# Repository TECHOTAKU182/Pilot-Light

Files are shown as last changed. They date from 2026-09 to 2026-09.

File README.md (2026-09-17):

# Pilot Light

一个紧凑型 USB RGB 状态信号灯的开源硬件项目。当前设计版本为 **SL25 Rev B**：通过 CH552G 控制一颗位于正面中心的 WS2812B-V5，使用单个直径 24 mm 的扩散灯窗显示红、黄、绿等状态。

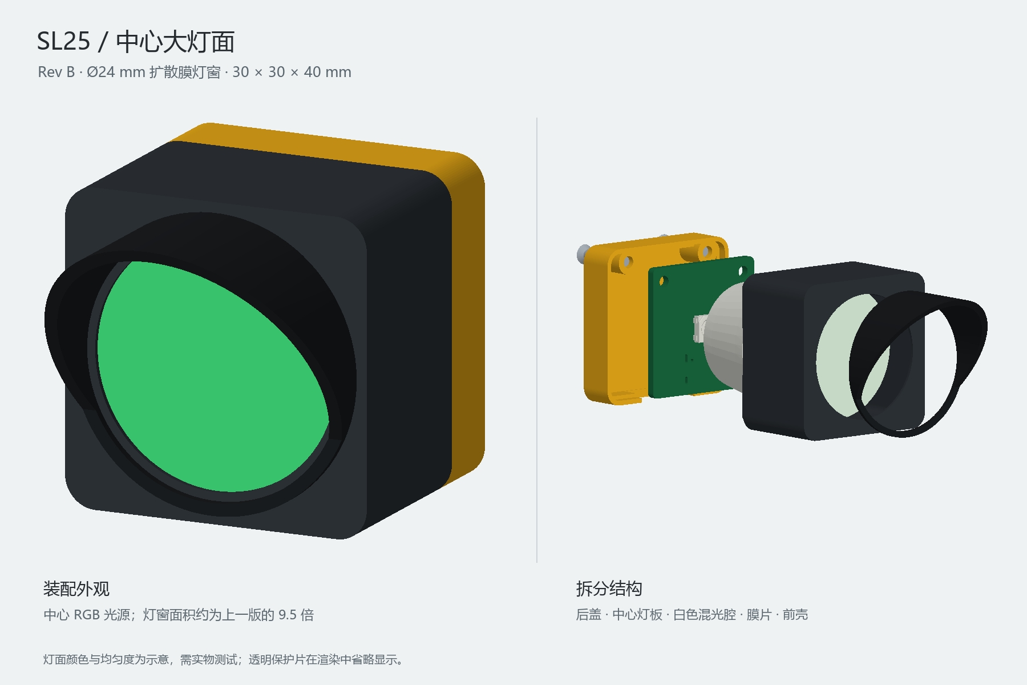
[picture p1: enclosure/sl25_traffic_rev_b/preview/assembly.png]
SL25 Rev B assembly preview


> 本仓库包含可编辑的 PCB、外壳和制造文件，但尚未完成实物打样、光学测试、USB 功能验证或电脑状态采集软件。制造与使用前请自行复核并完成测试。

## 当前设计

| 项目 | SL25 Rev B 规格 |
| --- | --- |
| PCB | 25 x 25 mm、双层、1.6 mm 厚 |
| 光源 | 正面中心 WS2812B-V5 RGB LED |
| 控制器 | CH552G，LED 数据输出为 P1.5 |
| 接口 | 背面 USB-C，USB 2.0 全速原型电路 |
| 外壳 | 30 x 30 x 40 mm |
| 灯窗 | 正面中心直径 24 mm，PET 扩散膜与透明 PC 保护片 |
| 遮光檐 | 顶部前伸 15 mm，两侧连续收短 |

该设计的光学结构从外到内依次为：黑色遮光帽、透明 PC 保护片、PET 扩散膜、泡棉压圈、白色混光腔与中心 RGB LED。白色混光腔是获得较均匀光效的必要零件，不能以黑色打印件替代。

## 仓库结构

| 路径 | 内容 |
| --- | --- |
| [`hardware/sl25_rev_b/`](hardware/sl25_rev_b/) | 当前 Rev B KiCad 工程、BOM、Gerber、贴片坐标、3D 模型与检查报告 |
| [`enclosure/sl25_traffic_rev_b/`](enclosure/sl25_traffic_rev_b/) | 当前 Rev B FreeCAD 工程、STEP、STL、光学片裁切模板与装配说明 |
| [`firmware/ch552_ws2812_demo/`](firmware/ch552_ws2812_demo/) | 用于焊后点灯检查的最小 CH552G 示例程序 |
| [`hardware/reference/`](hardware/reference/) | 器件数据手册和参考图纸 |
| [`SL25-RevB-complete.zip`](SL25-RevB-complete.zip) | Rev B 完整交付包 |
| [`hardware/SL25-RevB-gerbers.zip`](hardware/SL25-RevB-gerbers.zip) | Rev B PCB 制板文件包 |
| [`enclosure/SL25-Traffic-STL-RevB.zip`](enclosure/SL25-Traffic-STL-RevB.zip) | Rev B 3D 打印和膜片裁切文件包 |

`hardware/sl25/` 与 `enclosure/sl25_traffic/` 为历史 Rev A 文件，仅供参考。Rev A 和 Rev B 的 LED、元件安装面、外壳及控制方式不兼容，不能混用。

## 制造与装配

1. 使用 `hardware/SL25-RevB-gerbers.zip` 下单 PCB；建议规格为 FR-4、2 层、1.6 mm、1 oz 铜。
2. 根据 [`hardware/sl25_rev_b/BOM.csv`](hardware/sl25_rev_b/BOM.csv) 和 [`MATERIALS.md`](hardware/sl25_rev_b/MATERIALS.md) 采购并装配；所有元件和 USB-C 均在 PCB 背面，只有 WS2812B-V5 位于正面。
3. 打印 Rev B 的四个外壳件。前壳和遮光帽使用黑色材料，混光腔必须使用不透光白色材料；建议 PETG、0.4 mm 喷嘴、0.16-0.20 mm 层高。
4. 按 `cut_templates/` 中 1:1 SVG 裁切直径 26 mm 的透明 PC 保护片、PET 扩散膜和泡棉环；先测量模板中的 10 x 10 mm 校准框。
5. 参考 [外壳装配说明](enclosure/sl25_traffic_rev_b/README.md) 完成装配。需要两颗 M2 x 12、头径不超过 4.0 mm 的 90 度沉头螺丝。
6. 使用 [`firmware/ch552_ws2812_demo/`](firmware/ch552_ws2812_demo/) 的台架程序确认红、绿、蓝、黄依次点亮，再进行完整功能开发。

完整尺寸、材料规格、打印方向、光学叠层和拆装步骤见 [外壳 README](enclosure/sl25_traffic_rev_b/README.md)。电路、USB/LED 引脚、制造规则和检验结果见 [PCB README](hardware/sl25_rev_b/README.md)。

## 开发与重建

- PCB 使用 KiCad 10。更新设计时，先保留手工修改，再依次运行 `hardware/generate_rev_b.py`、`hardware/route_rev_b.py` 和 `hardware/finish_board.py`；这些生成流程会覆盖已有输出。
- 外壳使用 FreeCAD。修改 `enclosure/sl25_traffic_rev_b/parameters.json` 后，依次运行 `build.py`、`finish_cad.py`、`render.py` 和 `cut_templates.py`。
- 固件使用 SDCC，并需要 WCH CH55X EVT 提供的启动文件。示例程序只用于点灯检查，正式固件应加入 USB 枚举、主机命令超时关灯、USB 挂起关灯和看门狗。

## 验证状态与限制

仓库中的 ERC、DRC、制造文件、模型资产和几何干涉检查已通过，但以下事项尚待实物确认：

- USB 电气性能、枚举和 USB-C 兼容性
- LED 的 WS2812 时序、功耗、温升和各颜色亮度
- 扩散膜下的均匀度、色斑和黄色配比
- 3D 打印公差、膜材厚度、螺丝配合和机械耐久

本项目不是通过认证的交通信号灯，也不应在安全关键或监管用途部署。

## 许可证

尚未指定许可证。在许可证补充前，请先联系仓库所有者确认使用、修改和分发权限。

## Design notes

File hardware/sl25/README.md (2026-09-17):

# SL25 状态灯 PCB，Rev A

这是一块面向个人原型的 25 × 25 mm 双层 USB 状态灯 PCB，可用于正面宽、高均不超过 30 mm 的外壳。当前完成硬件设计和软件规则检查，尚未制作、焊接或实测。固件、Windows 状态采集程序和外壳工程不包含在本次交付中。

## 打开工程

使用 KiCad 10 打开 `sl25.kicad_pro`，分别进入原理图和 PCB 编辑器。符号、封装和所用 STEP 模型均随工程提供。KiCad 三维查看器可查看装配效果。

| 文件 | 内容 |
| --- | --- |
| `sl25.kicad_sch` | 单页原理图 |
| `sl25.kicad_pcb` | 已布线、铺铜的 PCB |
| `BOM.csv` | 逐项材料表，含准确型号与安装面 |
| `MATERIALS.md` | 中文采购及装配说明 |
| `checks/erc.rpt`、`checks/drc.rpt` | 最终规则检查报告 |
| `fabrication/` | Gerber、独立 PTH/NPTH 钻孔、贴装坐标 |
| `mechanical/sl25.step` | 含元件的装配 STEP，供外壳设计参考 |
| `mechanical/interface.json` | 板框、安装孔和接口位置 |
| `preview/` | 原理图 SVG 及 PCB 正反面、立体预览 |

本文件夹中的材料表替代之前讨论的 Pico 开发板和洞洞板采购方案。USB-C 插座必须匹配指定封装，不能仅凭“16 脚 Type-C”购买替代件。

## 电路

- USB-C 仅使用 USB 2.0 数据与 5 V 供电，CC1、CC2 各自用 5.1 kΩ 电阻接地。没有 USB PD 升压、电池或外部电源接口。
- CH552G 使用 SOP-16 窄体封装、内部振荡器和内部 USB 上拉。VCC 接 USB 5 V；V33 仅接 100 nF 去耦，不能短接到 5 V。
- USBLC6-2SC6 在背面保护 D+、D-；C4 是其电源去耦。插座金属壳直接接 GND，壳体焊脚直接接地铜皮。
- 单颗共阴 RGB 灯的每个阳极分别串 1 kΩ，限流后由 MCU GPIO 驱动。以 5.25 V 和 1% 电阻下限估算，即使忽略 LED 压降，单路电流也不超过 5.31 mA。
- JP1 平时保持断开；通过 10 kΩ 将 D+ 临时拉到 5 V，在上电时请求兼容工厂 USB ISP 的下载模式。购买带工厂 USB ISP 的 CH552G。TP3–TP6 保留专用编程器信号，不能当作通用 SPI 外设接口。
- R7 将高有效 RESET 下拉到 GND。固件仍应采用上电复位和看门狗。

| 功能 | CH552G 物理脚 | GPIO | 备注 |
| --- | --- | --- | --- |
| 红灯 | 3 | P1.5 | PWM1；高电平亮 |
| 绿灯 | 11 | P3.4 | PWM2；高电平亮 |
| 蓝灯 | 9 | P1.1 | 普通 GPIO，默认关闭 |
| USB D+ | 12 | P3.6 | USB 功能 |
| USB D- | 13 | P3.7 | USB 功能 |
| RESET | 6 | RST | 高有效 |

红加绿形成黄色。PWM 占空比需在样板和最终灯罩上调整，不能保证两路相同占空比就得到视觉上均匀的黄色。

## 固件与电脑端约定

建议后续固件使用 USB HID 接收颜色、亮度和灯效命令，Windows 程序通过 HID 库发送，无需增加 USB 转串口芯片。未配置、USB 挂起和主机命令超时应关闭 LED；初始化时先将三路输出置低，再使能输出，红绿用硬件 PWM，蓝色默认不用。

USB VID/PID 和描述符在固件阶段确定，不能未经授权用于发布产品。USB 功耗描述和挂起电流必须与实测匹配。当前电路未验证 USB 枚举、信号质量、EMC 或 ESD 性能；放置保护器件不等于通过系统级认证。

Windows 桌面版 Codex 的实时状态来源仍需单独验证。PCB 本身只接收灯光命令，不会自动读取 Codex。

## 制板与机械

建议首批 5 块样板：双层 FR-4、1.6 mm、1 oz 铜、绿色阻焊、白色丝印；优先选择平整表面处理，USB-C 手焊可选沉金。没有阻抗控制声明。

布线宽度 0.20 mm，设计最小铜间距 0.15 mm；过孔 0.60 / 0.30 mm。安装孔 2.20 mm，LED 孔 0.90 mm；PTH 和 NPTH 分开导出。USB4105 厂家推荐焊盘到定位孔的最近距离约 0.194 mm，本项目孔到铜间距规则设为 0.18 mm；下单时需要工厂支持这一要求。没有通过忽略 DRC 错误来放行设计。

板框圆角半径 1 mm。以 PCB 左上角为平面坐标原点，X 向右、Y 向下：

| 项目 | 位置或尺寸，mm |
| --- | --- |
| PCB 外形 | 25 × 25 × 1.6 |
| H1、H2 安装孔 | (2.7, 2.7)、(22.3, 2.7)，孔径 2.2 |
| D1 光学中心 | (12.5, 3.5)，靠近板上边，不在板中心 |
| USB 插座封装原点 | (12.5, 21.15)，插拔方向朝下边 |
| USB 插座本体 | 厂家宽 8.94、长 7.35、高 3.31 |
| LED 引脚孔 | X=9.2615 / 11.4205 / 13.5795 / 15.7385；Y=3.5 |

建议外壳先按 30 × 30 × 25 mm 预留，厚度尚未与用户锁定。壁厚与装配间隙需在外壳建模时分配，底面需留出 U2、C4 和焊点空间。两个 M2 安装柱配合底部承托或导轨固定 PCB，避免 USB 插拔力只作用在焊脚上。

LED 需用工具夹住靠近封装的一段引脚，再将外侧引脚整形成 2.159 mm 间距，封装底面离板约 3 mm，不要紧贴树脂根部弯折。灯珠顶面及焊接公差在外壳内至少按板上方 12.5 mm 预留，再留混光距离。STEP 中 LED 为通用 KiCad 模型，蓝色外观只是模型材质；实际指定灯珠为透明 RGB。该模型不能替代实物高度和透光测试。

STEP 使用 PCB 左上角 `(100,100)` 作为导出原点；CAD 的 Y 轴可能与上述 PCB 屏幕坐标相反，导入后以安装孔和 USB 方向识别朝向。

## 验证状态

2026-09-05 使用 KiCad 10.0.6：ERC 为 0 错误、0 警告；DRC 为 0 违规、0 未连接、0 原理图一致性问题。检查了厂家引脚图、封装尺寸图和正反面三维预览。

这些是设计文件检查，不能替代打样验证。未执行固件烧录、供电测量、USB 插头正反插、亮度混色、热稳定、休眠恢复及外壳装配测试。USB 数据布线为短距离原型布线，未做阻抗提取或信号完整性仿真。

## 设计依据与库许可

- WCH CH552/CH551 数据手册 V1G，第 3–4、19、31–33、70 页；`../reference/CH552.pdf` 为 WCH 原文的 Adafruit 镜像。厂家入口：https://www.wch-ic.com/downloads/CH552DS1_PDF.html
- Kingbright WP154A4SUREQBFZGC，第 1–2 页：https://www.kingbrightusa.com/images/catalog/spec/WP154A4SUREQBFZGC.pdf
- GCT USB4105 厂家图纸：https://gct.co/files/drawings/usb4105.pdf
- ST USBLC6-2SC6：https://www.st.com/resource/en/datasheet/usblc6-2.pdf
- ch55xduino 工程及 USB ISP 上电方式：https://github.com/DeqingSun/ch55xduino
- 随附封装、STEP 模型来自 KiCad 官方库，适用 KiCad 库许可及其例外：https://www.kicad.org/libraries/license/ 。通用芯片模型只表示封装，并不代表芯片品牌或实物标识。

## 重新生成

已交付文件可以直接在 KiCad 中编辑。只有需要重新生成初始设计时才执行以下脚本；重新生成会覆盖手工改板结果，先保留自己的修改。

在项目根目录运行 KiCad 自带 Python：依次执行 `hardware/generate_board.py`、`hardware/route_board.py`、`hardware/finish_board.py`。默认工具路径是本机的 `E:/Kicard`，其他电脑可调整 `KICAD_FOOTPRINT_DIR`、`KICAD_3DMODEL_DIR`。渲染需要 KiCad 用户缓存目录可写，否则可能只显示裸板。

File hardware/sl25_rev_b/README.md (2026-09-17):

# SL25 Rev B：中心 RGB 光源 PCB

本版与 `../../enclosure/sl25_traffic_rev_b/` 外壳配套，取代 Rev A 的偏上小灯珠设计。**PCB 正面只有一颗位于几何中心的 WS2812B-V5，其他电子元件和 USB-C 均在背面。** 板框仍为 25×25 mm，双层、1.6 mm 厚，两个 M2 孔的位置保持原接口。

此版灯珠、电阻值、元件安装面和固件灯光控制方式均与 Rev A 不同。制板、买料和装壳应整套使用 Rev B，不能把旧灯珠或旧外壳混入新版。

## 工程与生产文件

| 文件 | 内容 |
| --- | --- |
| `sl25.kicad_pro` / `.kicad_sch` / `.kicad_pcb` | KiCad 10 工程、原理图及已布线 PCB |
| `BOM.csv` / `MATERIALS.md` | 新版电子材料表、安装面与装配要求 |
| `fabrication/` | 双面 Gerber、分开的 PTH / NPTH 钻孔、贴片坐标和钻孔图 |
| `mechanical/sl25.step` / `interface.json` | 带元件的 STEP 与外壳接口 |
| `preview/` | PCB 正反面和立体预览、原理图 SVG |
| `checks/` | ERC、DRC、关键引脚与模型检查 |
| `SL25.pretty/`、`models/`、`SL25.kicad_sym` | 随工程提供的封装、模型和符号 |

建议原型制板：FR-4、2 层、1.6 mm、1 oz、常规阻焊。可以选白色阻焊，但混光主要依靠独立白色腔体，不依赖阻焊颜色。元件坐标文件已标明正反面，下单贴片时仍应与预览核对。

布线主宽 0.20 mm，过孔 0.60/0.30 mm；USB4105 定位孔与焊盘的厂家图形存在约 0.194 mm 间距，孔到铜最小规则沿用 0.18 mm。下单前确认制板方支持这一孔铜间距。

## 电路变化

CH552G、USB-C、USBLC6 ESD 保护、独立 5.1k CC 电阻和 USB ISP 触点保持原电路功能。D1 换为 5 V 四脚贴片 WS2812B-V5，内部集成 RGB 驱动。

| 信号 | 连接 |
| --- | --- |
| LED 数据 | CH552G 物理脚 3 / P1.5，经 R3=330Ω 到 D1 DIN |
| DIN 默认电平 | R4=100kΩ 下拉到 GND |
| D1 电源 | 1=+5V，3=GND；C5=100nF 为局部旁路 |
| D1 数据 | 4=DIN，2=DOUT 不连接 |
| USB 数据 | CH552G 12=D+、13=D−，经 USBLC6 保护接 USB-C A/B 对应引脚 |
| V33 | CH552G 16，只接 C2=100nF，不向其他元件供电 |
| RESET | CH552G 6，经 R7=10kΩ 下拉 |
| ISP | JP1 上电时临时通过 R6=10kΩ 将 D+ 拉高，平时断开 |

删除旧 R5 和三路 LED 1k 限流方式；R3、R4 已改作数据信号用。输入 C3 增至 4.7µF，5 V 电源上的外加电容名义总量为 5.0µF，V33 的 100nF 单独计算。不要按旧版的 1k 电阻表装配。

## 固件接口

新灯不接受旧版三路 GPIO PWM。需使用 800 kbit/s 的 24 位 **GRB、最高位先发** 数据；帧间低电平复位应大于 280µs。MCU 应在启动、USB 未配置、USB 挂起及主机命令超时时发送全零关灯帧。初始化 P1.5 为低电平，再启用输出。

数据手册在 12mA 条件下给出各色亮度，RGB 全亮可按约 36mA 加静态电流作初步功耗估算，但这不是整机最大电流保证。实际亮度、USB 功耗描述及挂起电流必须按样板测量确定。建议先从低亮度测试红、绿和红绿混合黄色。

本次交付是 PCB 和机械设计，没有编写或验证固件、USB 枚举和电脑状态采集程序。VID/PID 在固件阶段确定。

## 机械接口

PCB 顶视图坐标：左上角为 (0,0)，X 向右，Y 向下。

| 项目 | 位置或尺寸，mm |
| --- | --- |
| 板框 | 25×25，圆角 1，名义厚度 1.6 |
| D1 封装与光学中心 | **(12.5,12.5)**，正面；焊接方向 180° |
| D1 主体 | 5.4×5.0，厂家高度 1.57±0.05；外壳按板上方 1.7 留量 |
| D1 引脚朝向 | 正视 PCB 时：1 在右下，2 在右上，3 在左上，4 在左下；切角为 3 脚 |
| 安装孔 | H1 (2.7,2.7)，H2 (22.3,2.7)，孔径 2.2 |
| USB-C | 背面，封装原点 (12.5,21.15)，朝板的下边插拔 |
| 背面元件最低点 | 参考 STEP 为板背面下方约 3.395 |

装入外壳后，D1 与 Ø24 mm 灯窗同轴，中心均为外壳正视图 (15,15)。白色混光腔平底压在正面阻焊表面，中心 8×8 mm 缺口让开 LED 及焊盘；不得在正面加装其他元件或留下突起焊料。

## 检查与限制

KiCad ERC、DRC、未连接和原理图一致性检查均通过。关键检查还包括 WS2812B 引脚、GPIO 数据路径、CC 电阻、V33、RESET、ISP、正反安装面、灯珠中心和本地模型路径。参考模型已与外壳做体积干涉检查。

尚未打样、通电、验证 USB 信号完整性或测试光学均匀度。USB 是短走线的全速原型，没有阻抗控制或认证声明。PCB 预览中灯珠顶面颜色来自通用模型，不代表点亮或实物膜片效果。

## 设计依据与重建

- [Worldsemi WS2812B-V5 数据手册](https://www.world-semi.co.kr/_files/ugd/89cd03_1023b0e9d135431aa1e6491bfc318112.pdf)，机械及引脚见第 2 页，电气和时序见第 3–4 页；本地副本 `../reference/WS2812B-V5.pdf`。
- [GCT USB4105 厂家图纸](https://gct.co/files/drawings/usb4105.pdf)，本地副本 `../reference/USB4105.pdf`。
- [WCH CH552 数据手册入口](https://www.wch-ic.com/downloads/CH552DS1_PDF.html)，本地副本 `../reference/CH552.pdf`。
- [ST USBLC6-2 数据手册](https://www.st.com/resource/en/datasheet/usblc6-2.pdf)。
- 封装和通用 STEP 模型来自 [KiCad 官方库](https://www.kicad.org/libraries/license/)，适用其库许可及例外。

使用 KiCad 自带 Python 依次运行 `../generate_rev_b.py`、`../route_rev_b.py`、`../finish_board.py 本目录路径`；生成过程覆盖已有新版输出，应先保留自己的手工改动。默认 KiCad 安装于 `E:/Kicard`，其他机器可通过环境变量调整库路径。

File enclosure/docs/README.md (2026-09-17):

# SL25 Rev B：中心大灯面信号灯外壳

本版面向重新设计的 `../../hardware/sl25_rev_b/` PCB。**灯珠和灯窗均位于正面几何中心 (15,15)，可见灯窗直径 24 mm**，通光面积约 452 mm²，是 Rev A Ø7.8 mm 窗口的约 9.47 倍。仍是一个灯窗切换红、黄、绿。

外形 **30×30×40 mm**，由 25 mm 深的主体和最长前伸 15 mm 的遮光檐组成。正面保持 30×30 mm 限制；本次加长只改变外部遮光檐，壳内 USB 空间和混光距离保持原设计。

## 文件与结构

| 文件 | 用途 |
| --- | --- |
| `cad/SL25_Traffic_B.FCStd` | FreeCAD 原生可编辑工程，保留基础几何及布尔历史 |
| `cad/SL25_Traffic_B_assembly.step` | 壳体、光学叠层、PCB 元件及简化螺丝装配 |
| `stl/01_rear_cover.stl` | 后盖，建议黄色 |
| `stl/02_front_housing.stl` | 前壳，黑色；已转为正面朝打印平台 |
| `stl/03_signal_hood.stl` | 遮光帽，黑色；粘接面朝平台 |
| `stl/04_mixing_cup.stl` | **白色混光腔**，平底朝平台；不能用黑料代替 |
| `cad/05_*.step`、`06_*.step`、`07_*.step` | 扩散膜、透明保护片及泡棉圈的装配参考，不是打印件 |
| `cut_templates/` | 三种片材的 1:1 SVG 裁切轮廓及带 10 mm 校准方框的排版图 |
| `preview/assembly.png`、`dimensions.png` | 装配效果与尺寸图 |
| `checks/validation.json` | 实体、网格、干涉、居中及取出路径检查 |
| `parameters.json`、`build.py` | 参数化生成脚本；修改 JSON 后需重新运行 |

STL 导入切片软件时使用毫米、100% 比例，保持各文件已经设好的朝向。STEP 保留装配位置，STL 使用各自的打印坐标。请使用同版 PCB；Rev A 的直插 LED 和 USB 安装面不兼容。

## 光学叠层

从外到内依次是：黑色遮光帽与前壳窗口、透明 PC 保护片、PET 扩散膜、泡棉压圈、白色锥形混光腔、中心 RGB 光源。

| 项目 | 规格，mm |
| --- | --- |
| 可见灯窗 | Ø24，中心 (15,15)，占正面宽度 80% |
| 透明保护片 | Ø26 × 0.5，透明 PC，单片 |
| 扩散膜 | Ø26 × 0.2，LED 照明用 PET 扩散膜，单片 |
| 泡棉环 | 外径 26、内径 24，自由厚 0.5，装配压缩至约 0.3 |
| 安装凹槽 | Ø26.4，片材径向间隙 0.2 |
| LED 高度预留 | 名义板正面上方 1.7，兼顾 1.57 mm 灯体和焊接余量 |
| 光源至膜片背面 | 按上述最大高度计算至少 **13.5** |
| 白色混光腔 | 后部外径 20.4、前缘外径 26.2；底厚 0.8，中心 LED 缺口 8×8 |
| 遮光帽 | 外径 28、内径 25.6；顶部前伸 15、两侧中部约 4.81，连续收短至 0.8 厚安装环，缺口朝下 |

膜片和保护片**夹持固定，不粘死**。泡棉圈位于通光区域外，补偿厚度及打印公差；白色混光腔由 PCB 平面支撑。前壳采用四个角部定位舌，中部留出了混光腔及膜片的抽出空间。

遮光檐前缘采用斜切形成的连续曲线，上部长、两侧渐短。顶部最长处为 15 mm；粘接环和安装位置保持不变，已打印前壳时可单独更换 `03_signal_hood.stl`。遮光檐壁厚为 1.2 mm，长檐避免受挤压；粘接后再搬动整机。

造型参考开放式交通信号灯的遮光檐。[Aldridge Traffic Systems 配件资料，第 37 页](https://www.trafficltd.com.au/wp-content/uploads/2022/03/Lantern_Hardware_Accessories.pdf)列出的 200 mm 和 300 mm 灯面，其开放式遮光檐分别长 200 mm 和 300 mm。本设计按用户确认的 15 mm 最长前伸量定尺寸，与 Ø24 mm 灯窗之比为 0.625，采用较紧凑的渐短造型，并非道路信号灯的等比例复制。

选择均匀的照明用扩散膜，采购时核对实际厚度并索取雾度、透过率信息；不要拿偏光片、棱镜增亮片或普通透明包装膜代替。先用高雾度样片试光，再根据亮度和中心亮斑调整膜材。白色混光腔可轻磨内表面，保持洁净；不必粘金属箔。

效果图中的整面均匀颜色是设计示意，**不是光学仿真或实测结果**。单颗 RGB 的亮斑、色斑、黄色配比和亮度必须通过样板确认；扩散膜面积增大并不保证均匀度自动达标。

## 打印与五金

四个打印件建议使用 PETG，0.4 mm 喷嘴、0.16～0.20 mm 层高，至少 3 道外壁。前壳及遮光帽用黑料，混光腔必须用不透光白料；后盖可黄色或黑色。打印方向通常不需支撑，切片时检查 USB 开口桥接和小尺寸薄壁。

前壳主壁厚 1.5，前面板总厚 1.5，片材凹槽前方的局部压边厚 0.5；后盖底板 1.6，角部配合外唇 0.9。后盖台阶和前壳角舌单边间隙 0.2。模型中的 0.2 mm 扩散膜、0.5 mm PC 片和泡棉环应裁切，不能用 FDM 打印代替。

使用 **2 颗 M2×12、90° 沉头螺丝，头径不超过 4.0 mm**，长度按含头总长计。后盖通孔 Ø2.3、前壳导孔 Ø1.7，导孔深 4.6；名义啮合长度 3.4，尖端距盲孔底余量 1.2。先清理、试配和攻 M2 螺纹，再放入 PCB；轻拧即可。

仅遮光帽需少量适配所用塑料的胶粘接。不要把胶涂到扩散膜、保护片或白色腔体内，也不要用拧紧螺丝的方式强行压平明显超厚的叠层。

## 装配

1. 打印、去毛刺、攻丝，裁切 Ø26 的保护片、扩散膜和泡棉环。按 100% 打印裁切排版时，先测量图上的 10×10 mm 校准框。
2. 前壳正面朝下，从后方先放透明保护片，再放扩散膜，最后放泡棉环。撕去保护片自带运输膜，避免将其混入光学叠层。
3. 插入白色混光腔，大口朝膜片，小方孔朝 PCB。确认边缘落位、膜片平整。
4. PCB 正面 LED 朝白色腔体，从后方放入；LED 对准 8×8 mm 方孔，USB 位于背面并朝底部插口。
5. 盖上后盖，两颗 M2×12 螺丝穿过后盖和 PCB 孔后拧入前壳安装柱，交替轻拧，泡棉仅压至接缝自然闭合。
6. 先试光和试插 USB；确认后再把遮光帽粘到前壳正面，缺口朝 USB 方向。

拆卸顺序为拔线、退出螺丝、取下后盖、PCB、混光腔，再取膜片。模型已检查上述零件能沿后方直线退出。

PCB 在壳内左下角为 (2.5,2.5)，背面 Z=7，名义正面 Z=8.6。USB-C 开口 13×6.8，中心 X=15、Z=5.26，按不大于 12×6 mm 的线头塑料外壳检查。接口与线头金属伸出长度仍需以实物试插确认。

## 验证与重建

四个打印件均是有效单一实体，导出的 STL 封闭且无非流形边。零件两两、与 PCB 元件模型的体积干涉检查通过；PCB、混光腔及三种光学片材的后方取出路径检查通过；膜片中心误差为 0。螺纹啮合、泡棉真实变形和胶层未建模。

PCB STEP 中板厚约 1.51 mm，而实际设计采用名义 1.6 mm；安装柱和混光腔按后者设计。打印前测量实际板厚及膜材厚度，有偏差时调整参数，不用强拧补偿。尚未打样、点亮或测试机械耐久和光学效果。

FreeCAD 工程可直接打开编辑；主要参数改在 `parameters.json`，再依次运行 `build.py`、`finish_cad.py`、`render.py`、`cut_templates.py`。本机使用 `E:\freecad\bin\python.exe`，库路径可用 `FREECAD_LIB` 调整。生成过程会覆盖该版输出，应先保存自己的手工修改。

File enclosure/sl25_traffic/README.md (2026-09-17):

# SL25 单灯交通信号灯外壳，Rev A

本版配合现有 SL25 Rev A PCB，以**单个圆形灯窗、上方遮光帽、黑色前壳和黄色后盖**表达交通信号灯外形。同一个灯窗切换红、黄、绿，没有三颗分别点亮的灯。PCB 无需修改。

整机外形 **30 × 30 × 25 mm**，深度包含遮光帽。正面满足宽、高均不超过 30 mm 的约束；25 mm 深度仍是本次设计假设。外壳使用四个打印件和两颗螺丝，尚未打印试装。

## 文件

| 文件 | 用途 |
| --- | --- |
| `cad/SL25_Traffic_A.FCStd` | FreeCAD 1.1 原生工程，保留基础几何体和布尔运算历史、零件颜色及 PCB 参考模型 |
| `cad/SL25_Traffic_A_assembly.step` | 含四个壳体零件、PCB 元件及简化螺丝的装配模型 |
| `cad/01_*.step` 至 `04_*.step` | 四个零件的独立 STEP，保持装配坐标 |
| `stl/01_rear_cover.stl` | 黄色后盖，打印底面已置于 Z=0 |
| `stl/02_front_housing.stl` | 黑色前壳，已翻转为正面朝打印平台、开口朝上 |
| `stl/03_signal_hood.stl` | 黑色遮光帽，环形粘接面朝打印平台 |
| `stl/04_diffuser.stl` | 柔光片，平放打印；也可用同尺寸磨砂透光片替代 |
| `preview/assembly.png` | 装配与拆分预览 |
| `preview/dimensions.png` | 外形与装配尺寸图 |
| `preview/color_states.png` | 同一个灯窗的红、黄、绿外观示意 |
| `preview/usb_underside.png` | 底部 USB-C 开口预览 |
| `checks/validation.json` | 实体、网格、干涉、拆装路径及接口检查结果 |
| `parameters.json`、`build.py` | 参数文件与生成脚本 |

STL 没有单位元数据，导入切片软件时使用 **毫米、100% 比例**。STL 为各自的打印坐标，不能直接作为装配位置叠放；装配查看使用 FCStd 或 STEP。预览是 CAD 几何渲染，灯色是示意，没有进行光学仿真。

## 结构尺寸

装配坐标为正视图 X 向右、Y 向上，Z 朝观察者；后盖外表面 Z=0，USB 朝 Y 负方向插拔。

| 项目 | 尺寸或位置，mm |
| --- | --- |
| PCB | 25 × 25，名义厚度 1.6；左下角 (2.5, 2.5)，板背面 Z=4.2 |
| PCB 安装孔 | (5.2, 27.3)、(24.8, 27.3)，与现有两个 M2 孔同轴 |
| 主体壁厚 / 前面板厚度 | 1.5 / 2.0 |
| 后盖底板 / 台阶外唇厚度 | 1.6 / 0.9；外唇仅高 1.6，装配后由前壳定位舌配合支撑 |
| 前壳定位舌 | 厚 1.2，伸入 1.6，单边配合间隙 0.20 |
| 圆形灯窗 | 中心 (15, 24)，通光直径 7.8 |
| 柔光片 | 直径 9.6、厚 1.0；安装凹槽直径 9.9、深 1.2；径向间隙 0.15 |
| 遮光帽 | 外径 11.0，内径 8.6，前伸 3.6；底部留缺口 |
| LED 高度空间 | 按板正面上方 12.5 预留，至柔光片背面另留 1.3 |
| 背面元件到底板 | 按 PCB 参考 STEP 最低元件计算为 0.965 |
| PCB 侧向 / 下边定位间隙 | 0.25 |
| USB-C 开口 | 宽 13.0、高 6.8；中心 X=15、Z=7.45 |
| 螺丝导孔 / 后盖通孔 | 直径 1.7 / 2.3 |
| 螺丝名义啮合长度 | 4.2；距盲孔底部余量 1.2 |

USB 开口按线头塑料外壳不大于 **12 × 6 mm** 检查，允许其前端伸至装配坐标 Y=2.4。参考插座金属前沿位于 Y=2.675；实际线头的金属插头伸出长度、肩部间距仍需与实物核对。不要仅根据 USB-C 金属口的尺寸选线。

## 打印与材料

| 零件 | 建议材料与颜色 | 数量 |
| --- | --- | --- |
| 前壳、遮光帽 | 黑色 PETG；PLA 可用于先行试装 | 各 1 |
| 后盖 | 黄色 PETG；也可全部用黑色材料 | 1 |
| 柔光片 | 半透明本色 PETG，打印后两面轻磨砂；或 1 mm 磨砂透光片 | 1 |
| 螺丝 | M2 × 10，90° 沉头，头径不超过 4.0；长度按沉头螺丝含头总长计 | 2 |
| 胶 | 少量适用于所选塑料的透明环氧胶；柔光片可用电子用中性固化硅胶 | 少量 |

建议 0.4 mm 喷嘴、0.16～0.20 mm 层高、3 道外壁。后盖 0.9 mm 台阶外唇应在切片预览中检查为连续两道壁；可使用可变线宽。各零件已按平放方向导出，通常不需支撑，但要检查 USB 开口的小跨度桥接。不要整机一体打印。

柔光片按实心打印，避免稀疏填充纹路；不建议直接用普通不透明白料代替透光材料。先用未粘接的柔光片测试亮度和混色，必要时调整材料或厚度。

先打印一套试装。打印孔可能偏小，清理后使用 M2 丝锥加工前壳的 1.7 mm 导孔，轻拧试配；不要强行拧入或打穿盲孔。前壳定位舌、后盖接合边和灯窗均应去毛刺，避免用过量拧紧力弥补配合误差。

## 装配顺序

1. 在放入 PCB 前清理所有打印件，修整通孔、沉孔及定位边，完成两个 M2 导孔攻丝。清除塑料屑。
2. 从前壳后方放入柔光片，使其贴住灯窗内侧台阶；确认不会穿过前方小孔。先不粘胶，接通已完成调试的 PCB 检查红、黄、绿混色和亮度。
3. 确认透光效果后，用少量胶固定柔光片外缘，避免胶进入通光区。遮光帽粘在前壳正面，缺口朝 USB 方向；待胶完全固化。
4. PCB 元件正面朝灯窗，从后方放入前壳；USB 朝底部开口，两个安装孔对准前壳螺丝柱。检查 LED 不顶柔光片、USB 不顶壳。
5. 装上后盖，后盖支撑柱托住 PCB 背面。两颗 M2×10 沉头螺丝从后盖穿过 PCB 孔后进入前壳柱，交替轻拧至接缝闭合。
6. 检查 USB 两种方向均可完全插入；轻拉线缆并检查接口周围、PCB 和灯窗无松动。拆卸时拔线、退出两颗螺丝，再沿后方取下后盖与 PCB。

PCB 实际板厚和 LED 焊接高度会影响装配。若板厚明显偏离 1.6 mm，先调整参数并重新生成，避免夹弯 PCB。背面焊点应剪短，不能超过已有元件的最低点；外壳没有给未修剪的长引脚留空间。

USB 从底部出线，适合背面贴附安装；本版未附带桌面支架。胶、螺丝和线缆尺寸以实际采购件试配为准。

## 验证范围

本版四个打印件均为有效单一实体，STL 封闭且无非流形边。检查了零件两两干涉、与现有 PCB 元件模型的干涉，以及 PCB 与后盖向后退出 0.2、1、2、4、8、16、25 mm 的路径，均未发现体积碰撞。12×6 mm 线头外壳包络与模型不碰撞。

螺丝为无螺纹的简化参考件；螺纹与导孔材料的预期啮合不作为干涉错误。KiCad 通用 LED 模型偏低，外壳采用更保守的板上方 12.5 mm 设计空间，而不是只按该模型的顶点设计。

这些检查不等于实物验证。尚未进行打印配合、透光混色、螺丝耐拆、线缆拉力、温升或防尘防水测试。硬件仍未打样，固件和电脑状态采集程序不包含在本次外壳交付中。

## 编辑和重新生成

FreeCAD 工程包含可编辑的基础实体与布尔历史，没有依赖自定义 CAD 插件。可在 FreeCAD 中编辑几何体；统一修改主要尺寸时，编辑 `parameters.json` 后运行生成脚本。FCStd 中的参数备注是记录，不是自动驱动所有几何的电子表格。

在本机 PowerShell 中执行以下命令。生成脚本会覆盖本目录的 CAD、STL、检查和预览文件，因此先保留自己的手工修改。

```powershell
& 'E:\freecad\bin\python.exe' 'E:\statues light\enclosure\sl25_traffic\build.py'
& 'E:\freecad\bin\python.exe' 'E:\statues light\enclosure\sl25_traffic\finish_cad.py'
& 'E:\freecad\bin\python.exe' 'E:\statues light\enclosure\sl25_traffic\render.py'
```

其他电脑可使用自己的 FreeCAD Python 环境，并设置 `FREECAD_LIB`。预览脚本另需 NumPy、Pillow 和中文字体；本机使用 FreeCAD 自带的 Python 库与微软雅黑。`finish_cad.py` 使用离屏 Qt，只保存可见性和颜色；工程本身无需运行脚本即可打开。

输入 PCB 的来源为 `../../hardware/sl25/mechanical/sl25.step`。完整交付包保留这一相对目录结构，便于重新生成。

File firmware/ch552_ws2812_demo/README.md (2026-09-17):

# SL25 Rev B CH552G 固件

这是用于焊后硬件检查的最小测试程序：上电后让中心 WS2812B-V5 依次显示红、绿、蓝、黄。LED 数据脚为 CH552G 的 P1.5（物理脚 3）。它不包含 USB HID 或电脑状态控制协议。

## 编译

从 WCH 的 CH55X EVT 中取得 `CH552.H`/启动文件，使用 SDCC 编译。不同版本 EVT 的启动文件和时钟初始化名称可能不同，因此本目录提供的是核心 `main.c`，需放入对应 EVT 示例工程中构建。编译结果应为 `.hex` 文件。

## 烧录

用 WCHISPTool 选择“8位 CH55X / CH552 / USB下载”。插 USB 前临时短接 PCB 的 JP1/BOOT；电脑识别后松开 JP1，再选择生成的 HEX 下载并校验。

## 注意

当前代码只适合台架点灯验证。正式使用前应加入 USB 枚举、主机命令超时关灯、挂起关灯和看门狗，并用示波器确认 WS2812 时序。不要把本文件烧到 CH551 或其他型号而不重新验证引脚和启动文件。

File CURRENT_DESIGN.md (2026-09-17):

# 当前设计：SL25 Rev B

Rev B 是中心大灯面版本：25×25 mm PCB，正面中心 WS2812B-V5，背面 USB-C；外壳 30×30×40 mm，中心 Ø24 mm 可见扩散膜灯窗。当前遮光檐顶部最长前伸 15 mm（1.5 cm），两侧渐短至安装环，檐长与灯面直径之比为 0.625。

- PCB 工程、材料与制造说明：`hardware/sl25_rev_b/README.md`
- 外壳、膜片与装配说明：`enclosure/sl25_traffic_rev_b/README.md`
- 完整交付包：`SL25-RevB-complete.zip`
- 制板文件包：`hardware/SL25-RevB-gerbers.zip`
- 打印与膜片裁切包：`enclosure/SL25-Traffic-STL-RevB.zip`

Rev A 保留为历史版本。两版灯珠、PCB 安装面、灯光控制方式和外壳不同，请勿混用。当前未完成实物打样、光学测试、固件或电脑状态采集程序。

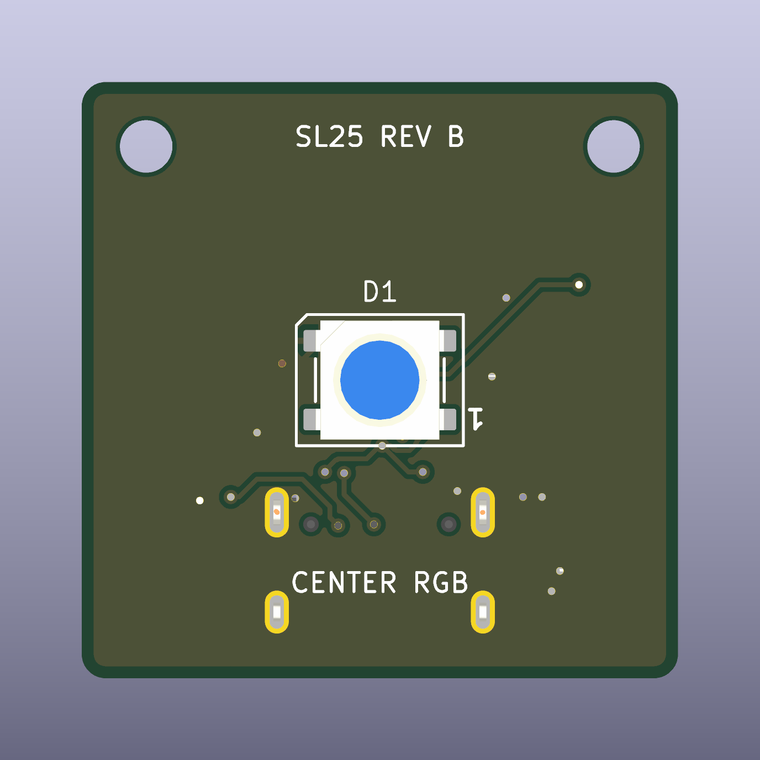
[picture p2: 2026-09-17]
SL25-RevB/hardware/sl25_rev_b/preview/board-top.png

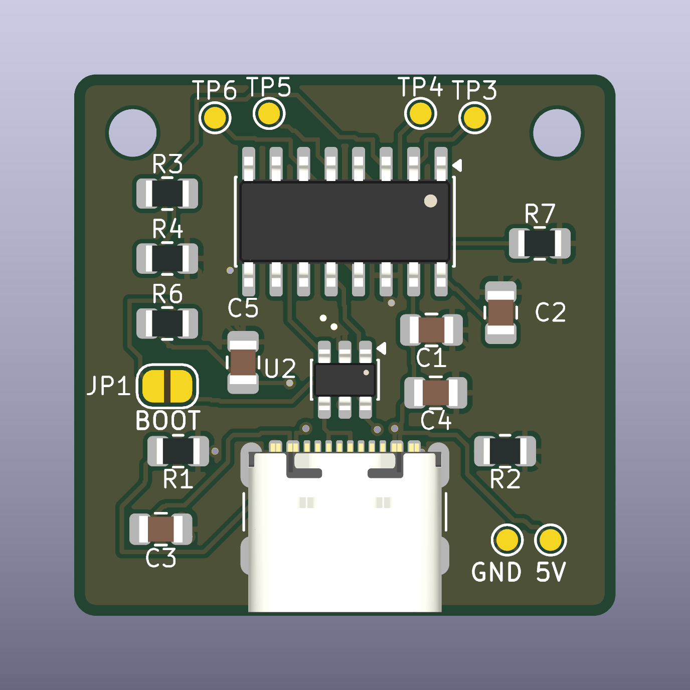
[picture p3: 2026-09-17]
hardware/sl25_rev_b/preview/board-bottom.png

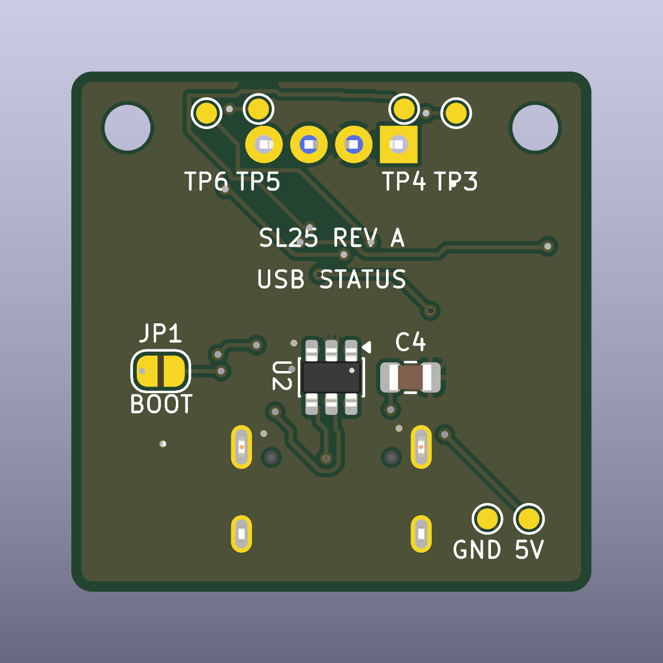
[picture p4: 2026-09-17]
hardware/sl25/preview/board-bottom.png

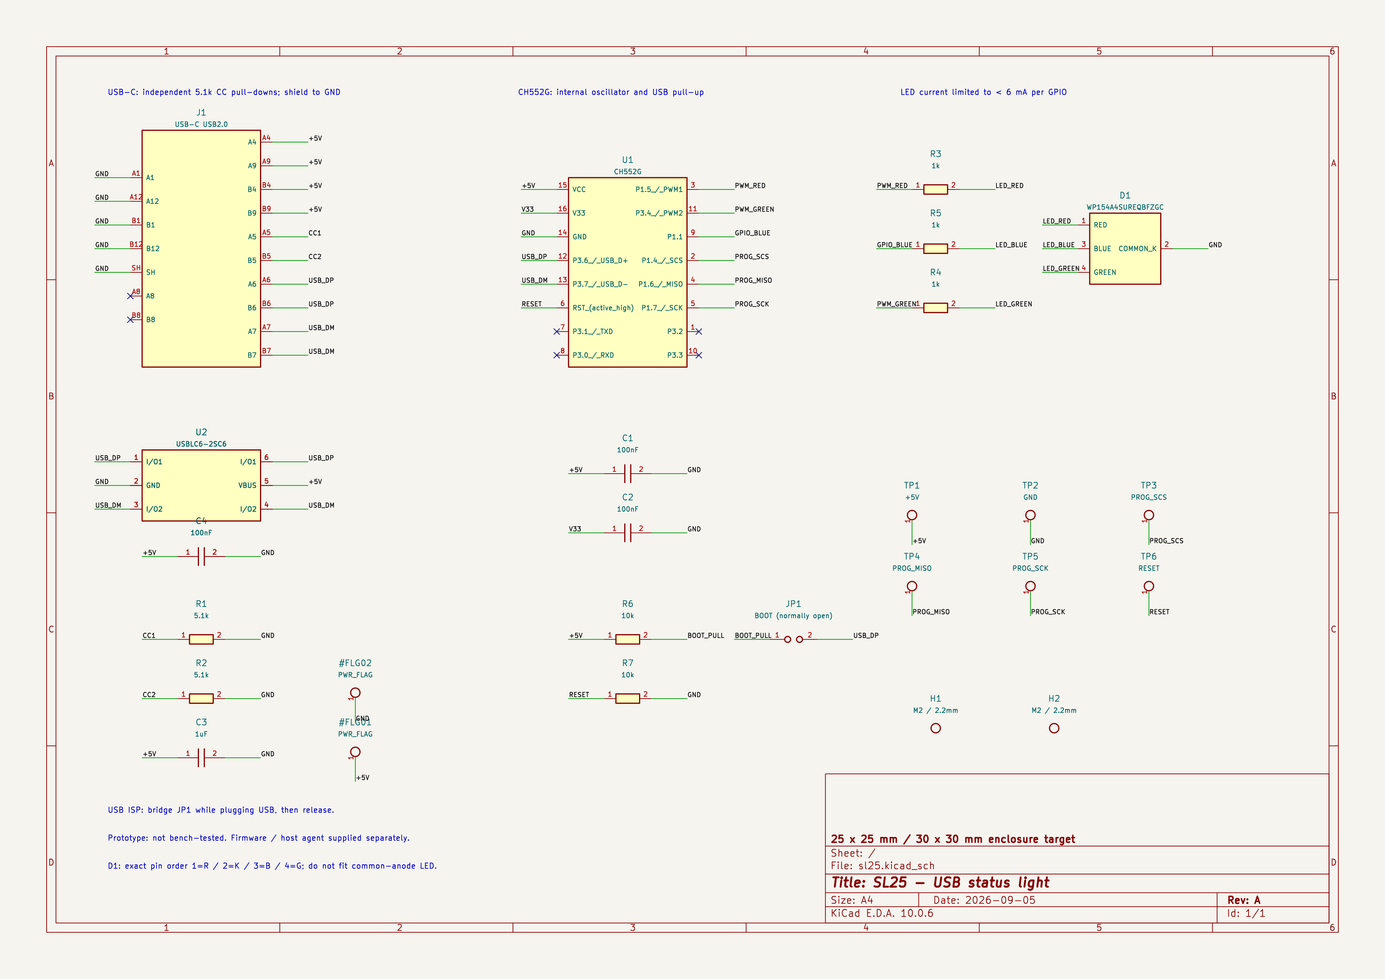
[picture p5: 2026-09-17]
hardware/sl25/preview/schematic.png

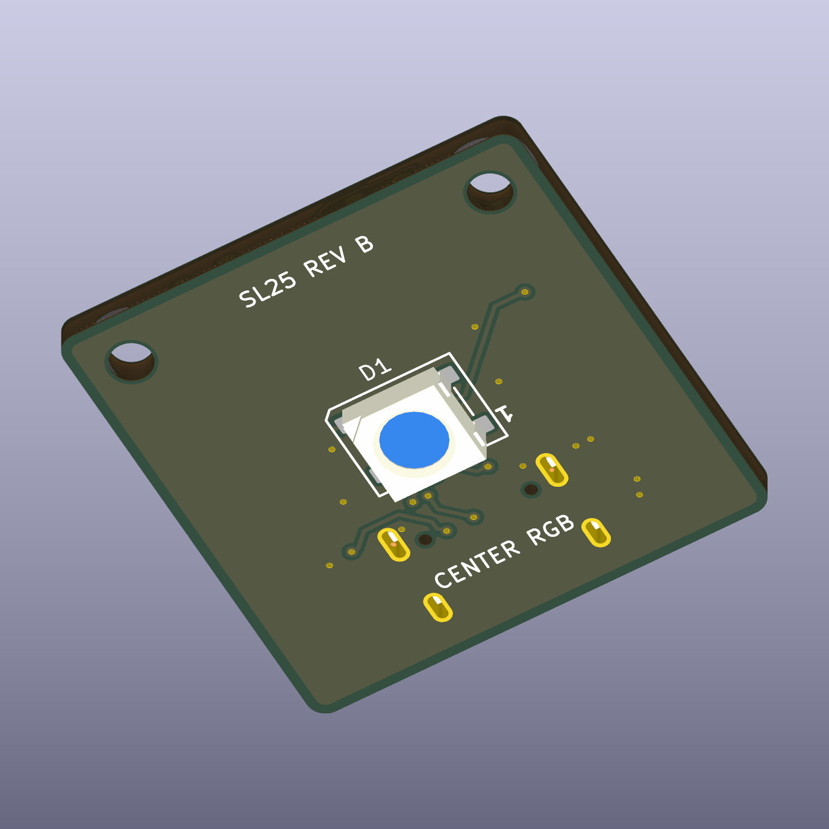
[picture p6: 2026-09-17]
SL25-RevB/hardware/sl25_rev_b/preview/board-isometric.png

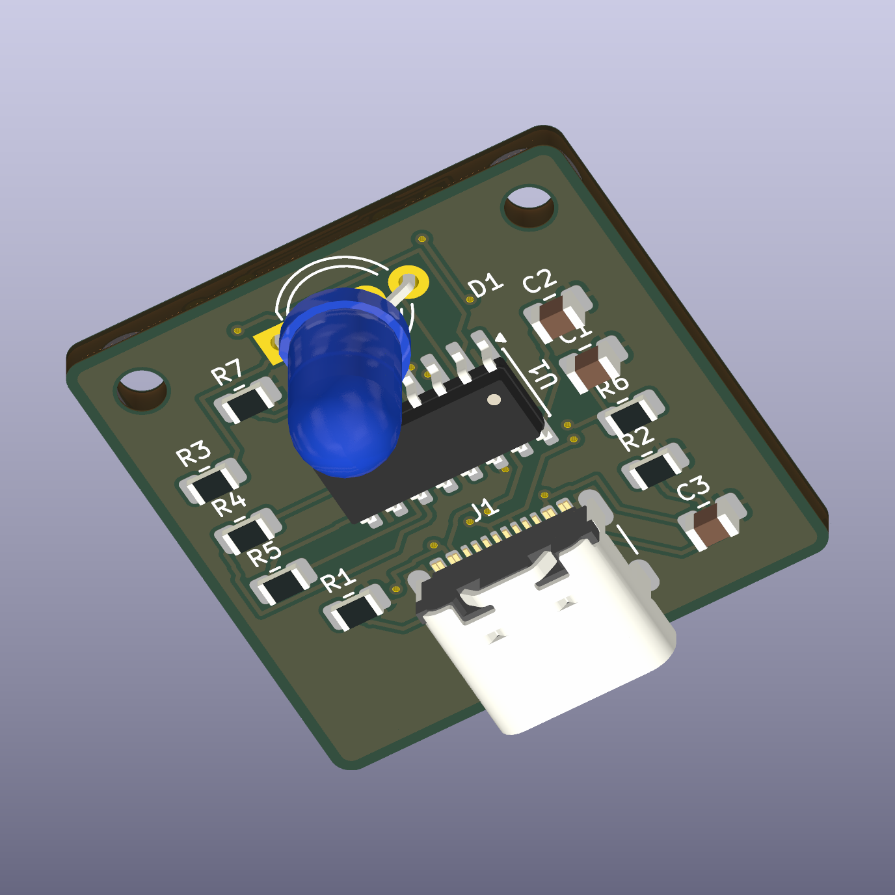
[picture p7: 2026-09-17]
hardware/sl25/preview/board-isometric.png

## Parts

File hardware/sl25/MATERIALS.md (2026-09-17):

# Rev A 材料与装配

此表替代早期的 Pico 开发板清单。先制作少量样板；这里不包含实时价格和商家库存承诺。

| 位号 | 采购规格 | 每块用量 | 建议购买 |
| --- | --- | --- | --- |
| PCB | SL25 Rev A，25 × 25 mm，2 层，1.6 mm | 1 | 5 块样板 |
| U1 | WCH CH552G，SOP-16 窄体，带工厂 USB ISP | 1 | 2–3 颗 |
| J1 | GCT USB4105-GF-A，16 接点 USB-C 母座 | 1 | 2 个 |
| U2 | ST USBLC6-2SC6，SOT-23-6 | 1 | 2–3 颗 |
| D1 | Kingbright WP154A4SUREQBFZGC，共阴 RGB | 1 | 2–3 颗 |
| R1、R2 | 5.1 kΩ，0805，1%，至少 1/8 W | 2 | 10 颗 |
| R3、R4、R5 | 1 kΩ，0805，1%，至少 1/8 W | 3 | 10 颗 |
| R6、R7 | 10 kΩ，0805，1%，至少 1/8 W | 2 | 10 颗 |
| C1、C2、C4 | 100 nF，0805，X7R，16 V | 3 | 10 颗 |
| C3 | 1 µF，0805，X7R，16 V | 1 | 10 颗 |
| 数据线 | 设备端 USB-C，电脑端匹配 USB-A 或 USB-C，支持数据 | 1 | 1 条 |

JP1、TP1–TP6 是 PCB 自带触点，H1、H2 是安装孔，均不用购买电子元件。M2 螺丝长度、安装柱、底座及柔光灯罩等外壳尺寸定稿后确定。旧清单中的 Micro-USB 线不适用此版。

灯珠封装原始脚距为 1.27 mm，PCB 使用宽脚孔距 2.159 mm，焊接前需要整形。不要买共阳灯、两脚自动变色灯；使用其他型号前必须核对 1=红、2=公共阴极、3=蓝、4=绿和实际引脚尺寸。

## 焊接顺序

1. 先装背面 U2、C4，检查 U2 的 1 脚方向和焊桥。
2. 装正面电阻、电容及 U1。U1 的 1 脚朝 PCB 右侧靠上，对照丝印三角和三维图，不按文字方向猜测。
3. 焊 USB-C 母座，先固定外壳脚，再处理细间距信号脚；使用助焊剂和放大检查，尤其注意 CC、D+、D- 相邻脚。
4. 将 RGB 灯引脚整形，离板约 3 mm 安装，核对平边、1 脚标记和公共阴极位置。
5. JP1 保持断开。清理残余助焊剂并检查背面所有焊点。

## 首次上电

1. 断电测量 TP1（5 V）和 TP2（GND）之间是否存在持续低阻短路；等待电容充电稳定后判断。
2. 使用限流 5 V 电源进行初次检查，限流先设为 50 mA；外接电源时拔掉电脑 USB，避免反向供电。检查 VCC、V33 和芯片温升，异常立即断电。
3. 拔掉外接电源。断电时临时桥接 JP1，然后插电脑 USB；出现兼容的 ISP 设备后松开 JP1。工厂 bootloader 不同配置的行为需以采购型号和 WCH 工具说明为准。
4. 固件阶段先做独立灯光测试，再接入 Codex。未烧录应用固件时，插 USB 不会自动显示工作状态。
5. 依次验证红、绿、蓝、红绿混色、亮度和呼吸；再测 USB-A 转 C、C 转 C、C 口正反插、拔插和电脑休眠恢复。

TP3=SCS/P1.4，TP4=MISO/P1.6，TP5=SCK/P1.7，TP6=RESET；它们是 WCH 专用编程器预留信号。普通 USB 转串口板不能直接替代这种编程器。

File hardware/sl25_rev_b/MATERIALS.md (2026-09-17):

# Rev B 电子材料与焊接

按本目录 `BOM.csv` 买料。下表为人工采购汇总，参考位号安装面以工程和预览为准。

| 材料 | 数量 | 安装面 / 注意事项 |
| --- | --- | --- |
| CH552G，SOP16 150mil | 1 | 背面；购买带工厂 USB ISP 的 G 型号 |
| GCT USB4105-GF-A USB-C | 1 | 背面；必须匹配指定封装 |
| USBLC6-2SC6，SOT-23-6 | 1 | 背面，U2 |
| Worldsemi WS2812B-V5，5050 四脚 | 1 | 正面，D1；不是旧版直插 RGB，也不是六脚 WS2812 |
| 0805，5.1kΩ，1% | 2 | R1、R2 |
| 0805，330Ω，1% | 1 | R3 |
| 0805，100kΩ，1% | 1 | R4 |
| 0805，10kΩ，1% | 2 | R6、R7；没有 R5 |
| 0805，100nF，X7R，16V | 4 | C1、C2、C4、C5，背面 |
| 0805，4.7µF，X7R，16V | 1 | C3，背面 |
| USB 数据线，设备端 USB-C | 1 | 塑料线头外壳建议不大于 12×6 mm |

电阻额定功率至少 0.125W。被动元件可各备少量余料。JP1 和 TP1–TP6 是 PCB 自带触点，不购买跳帽或插针。外壳螺丝和光学材料见新版机械说明。

先焊背面电阻、电容和芯片，再焊 USB-C，最后焊正面 LED。D1 正视 PCB 的 3 脚切角朝左上；务必以引脚位置和丝印对照，不把切角误认作 1 脚。LED 顶部胶体不要用镊子夹持或用烙铁接触。

装壳前确认 5V/GND 无短路，使用限流供电进行首次测试；外部供电时不要同时连接电脑 USB。先验证电源、烧录、USB 枚举和三个颜色，再放上白色混光腔与膜片试光。清理焊剂和飞锡，前面除 LED 区域外保持平整，避免混光腔底面被焊点顶起。

WS2812B 产品存在多种版本。若采购的是 V5/W、V6 或其他后缀，应先核对供应商对应数据手册的四脚映射、尺寸、电压、时序和电流；不能只看“5050 RGB”字样替换。

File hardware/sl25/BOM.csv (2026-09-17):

Reference | Value | MPN_or_specification | Footprint | Side | Quantity | Notes
J1 | USB-C USB2.0 | GCT USB4105-GF-A | Connector_USB:USB_C_Receptacle_GCT_USB4105-xx-A_16P_TopMnt_Horizontal | Top | 1 | Exact footprint required; USB-C socket is not interchangeable by appearance.
U1 | CH552G | CH552G | Package_SO:SOIC-16_3.9x9.9mm_P1.27mm | Top | 1 | SOP16 150mil. Buy with factory USB ISP bootloader; do not substitute CH552T/E/P.
U2 | USBLC6-2SC6 | USBLC6-2SC6 | Package_TO_SOT_SMD:SOT-23-6 | Bottom | 1 | Bottom side; pins 1/6 and 3/4 are internally connected line pairs.
D1 | WP154A4SUREQBFZGC | WP154A4SUREQBFZGC | LED_THT:LED_D5.0mm-4_RGB_Wide_Pins | Top | 1 | Form 1.27mm native leads to 2.159mm PCB pitch with 3mm standoff. 1=R, 2=common K, 3=B, 4=G. Clear lens needs diffuser.
R1 | 5.1k | 0805 5.1k 1% >=0.125W | Resistor_SMD:R_0805_2012Metric | Top | 1
R2 | 5.1k | 0805 5.1k 1% >=0.125W | Resistor_SMD:R_0805_2012Metric | Top | 1
R3 | 1k | 0805 1k 1% >=0.125W | Resistor_SMD:R_0805_2012Metric | Top | 1
R4 | 1k | 0805 1k 1% >=0.125W | Resistor_SMD:R_0805_2012Metric | Top | 1
R5 | 1k | 0805 1k 1% >=0.125W | Resistor_SMD:R_0805_2012Metric | Top | 1
R6 | 10k | 0805 10k 1% >=0.125W | Resistor_SMD:R_0805_2012Metric | Top | 1
R7 | 10k | 0805 10k 1% >=0.125W | Resistor_SMD:R_0805_2012Metric | Top | 1
C1 | 100nF | 0805 100nF X7R 16V | Capacitor_SMD:C_0805_2012Metric | Top | 1
C2 | 100nF | 0805 100nF X7R 16V | Capacitor_SMD:C_0805_2012Metric | Top | 1
C3 | 1uF | 0805 1uF X7R 16V | Capacitor_SMD:C_0805_2012Metric | Top | 1
C4 | 100nF | 0805 100nF X7R 16V | Capacitor_SMD:C_0805_2012Metric | Bottom | 1
JP1 | BOOT (normally open) | PCB touch pads | Jumper:SolderJumper-2_P1.3mm_Open_RoundedPad1.0x1.5mm | Bottom | 1 | Momentarily bridge during USB insertion; release after ISP enumeration. Do not solder closed.
TP1 | +5V | PCB test pad | TestPoint:TestPoint_Pad_D1.0mm | Bottom | 1 | Programmer pads use 5V signaling; disconnect USB before external power.
TP2 | GND | PCB test pad | TestPoint:TestPoint_Pad_D1.0mm | Bottom | 1 | Programmer pads use 5V signaling; disconnect USB before external power.
TP3 | PROG_SCS | PCB test pad | TestPoint:TestPoint_Pad_D1.0mm | Bottom | 1 | Programmer pads use 5V signaling; disconnect USB before external power.
TP4 | PROG_MISO | PCB test pad | TestPoint:TestPoint_Pad_D1.0mm | Bottom | 1 | Programmer pads use 5V signaling; disconnect USB before external power.
TP5 | PROG_SCK | PCB test pad | TestPoint:TestPoint_Pad_D1.0mm | Bottom | 1 | Programmer pads use 5V signaling; disconnect USB before external power.
TP6 | RESET | PCB test pad | TestPoint:TestPoint_Pad_D1.0mm | Bottom | 1 | Programmer pads use 5V signaling; disconnect USB before external power.
H1 | M2 / 2.2mm | M2 mounting hole | MountingHole:MountingHole_2.2mm_M2 | Top | 1
H2 | M2 / 2.2mm | M2 mounting hole | MountingHole:MountingHole_2.2mm_M2 | Top | 1

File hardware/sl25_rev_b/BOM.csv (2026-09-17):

Reference | Value | MPN_or_specification | Footprint | Side | Quantity | Notes
J1 | USB-C USB2.0 | GCT USB4105-GF-A | Connector_USB:USB_C_Receptacle_GCT_USB4105-xx-A_16P_TopMnt_Horizontal | Bottom | 1 | Bottom side, opens toward PCB +Y. Exact GCT USB4105-GF-A footprint required.
U1 | CH552G | CH552G | Package_SO:SOIC-16_3.9x9.9mm_P1.27mm | Bottom | 1 | Bottom side CH552G SOP16. P1.5 sends 800kbit/s GRB; Rev A PWM firmware is incompatible.
U2 | USBLC6-2SC6 | USBLC6-2SC6 | Package_TO_SOT_SMD:SOT-23-6 | Bottom | 1 | Bottom side; pins 1/6 and 3/4 are internally connected line pairs.
D1 | WS2812B-V5 | Worldsemi WS2812B-V5, 5050 PLCC4 | LED_SMD:LED_WS2812B_PLCC4_5.0x5.0mm_P3.2mm | Top | 1 | Centered at PCB (12.5,12.5). 1=VDD,2=DOUT NC,3=GND,4=DIN; corner notch at pin 3. GRB 800kbit/s, reset low >280us. Not the Rev A through-hole LED.
R1 | 5.1k | 0805 5.1k 1% >=0.125W | Resistor_SMD:R_0805_2012Metric | Bottom | 1
R2 | 5.1k | 0805 5.1k 1% >=0.125W | Resistor_SMD:R_0805_2012Metric | Bottom | 1
R3 | 330 | 0805 330 ohm 1% >=0.125W | Resistor_SMD:R_0805_2012Metric | Bottom | 1 | DIN series resistor; not an LED current limiter.
R4 | 100k | 0805 100k 1% >=0.125W | Resistor_SMD:R_0805_2012Metric | Bottom | 1 | DIN idle pull-down.
R6 | 10k | 0805 10k 1% >=0.125W | Resistor_SMD:R_0805_2012Metric | Bottom | 1
R7 | 10k | 0805 10k 1% >=0.125W | Resistor_SMD:R_0805_2012Metric | Bottom | 1
C1 | 100nF | 0805 100nF X7R 16V | Capacitor_SMD:C_0805_2012Metric | Bottom | 1
C2 | 100nF | 0805 100nF X7R 16V | Capacitor_SMD:C_0805_2012Metric | Bottom | 1
C3 | 4.7uF | 0805 4.7uF X7R 16V | Capacitor_SMD:C_0805_2012Metric | Bottom | 1 | USB input bulk decoupling; total nominal rail capacitance 5.0uF.
C4 | 100nF | 0805 100nF X7R 16V | Capacitor_SMD:C_0805_2012Metric | Bottom | 1
JP1 | BOOT (normally open) | PCB touch pads | Jumper:SolderJumper-2_P1.3mm_Open_RoundedPad1.0x1.5mm | Bottom | 1 | Momentarily bridge during USB insertion; release after ISP enumeration. Do not solder closed.
TP1 | +5V | PCB test pad | TestPoint:TestPoint_Pad_D1.0mm | Bottom | 1 | Programmer pads use 5V signaling; disconnect USB before external power.
TP2 | GND | PCB test pad | TestPoint:TestPoint_Pad_D1.0mm | Bottom | 1 | Programmer pads use 5V signaling; disconnect USB before external power.
TP3 | PROG_SCS | PCB test pad | TestPoint:TestPoint_Pad_D1.0mm | Bottom | 1 | Programmer pads use 5V signaling; disconnect USB before external power.
TP4 | PROG_MISO | PCB test pad | TestPoint:TestPoint_Pad_D1.0mm | Bottom | 1 | Programmer pads use 5V signaling; disconnect USB before external power.
TP5 | PROG_SCK | PCB test pad | TestPoint:TestPoint_Pad_D1.0mm | Bottom | 1 | Programmer pads use 5V signaling; disconnect USB before external power.
TP6 | RESET | PCB test pad | TestPoint:TestPoint_Pad_D1.0mm | Bottom | 1 | Programmer pads use 5V signaling; disconnect USB before external power.
H1 | M2 / 2.2mm | M2 mounting hole | MountingHole:MountingHole_2.2mm_M2 | Top | 1
H2 | M2 / 2.2mm | M2 mounting hole | MountingHole:MountingHole_2.2mm_M2 | Top | 1
C5 | 100nF | 0805 100nF X7R 16V | Capacitor_SMD:C_0805_2012Metric | Bottom | 1 | Local RGB LED supply bypass, bottom side near D1 pin 1 via.

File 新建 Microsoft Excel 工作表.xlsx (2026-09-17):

元件 | 位号 | 规格 / 型号 | 数量 | 位置
主控芯片 | U1 | CH552G，SOP16 | 1 | 背面
USB 静电保护芯片 | U2 | USBLC6-2SC6，SOT-23-6 | 1 | 背面
USB-C 接口 | J1 | GCT USB4105-GF-A | 1 | 背面
RGB 灯珠 | D1 | WS2812B-V5，5050 四脚贴片 | 1 | 正面
电阻 | R1、R2 | 5.1kΩ，0805，1% | 2 | 背面
电阻 | R3 | 330Ω，0805，1% | 1 | 背面
电阻 | R4 | 100kΩ，0805，1% | 1 | 背面
电阻 | R6、R7 | 10kΩ，0805，1% | 2 | 背面
电容 | C1、C2、C4、C5 | 100nF，0805，X7R，16V | 4 | 背面
电容 | C3 | 4.7µF，0805，X7R，16V | 1 | 背面

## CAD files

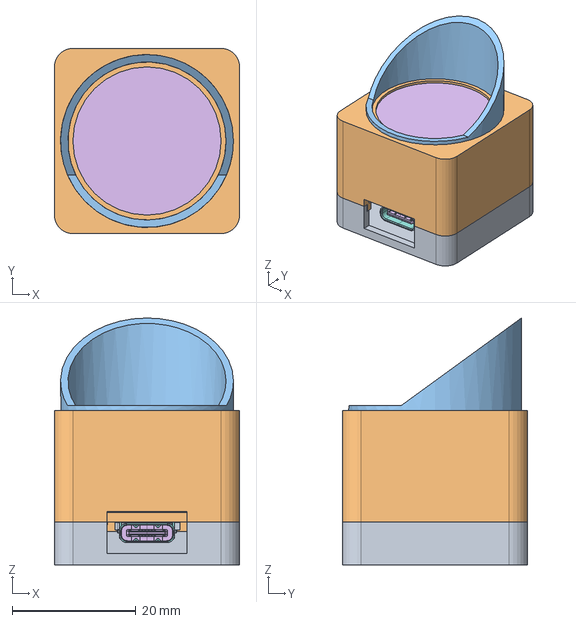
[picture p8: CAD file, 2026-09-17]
enclosure/sl25_traffic_rev_b/cad/SL25_Traffic_B_assembly.step
30.0 x 30.0 x 40.0 mm

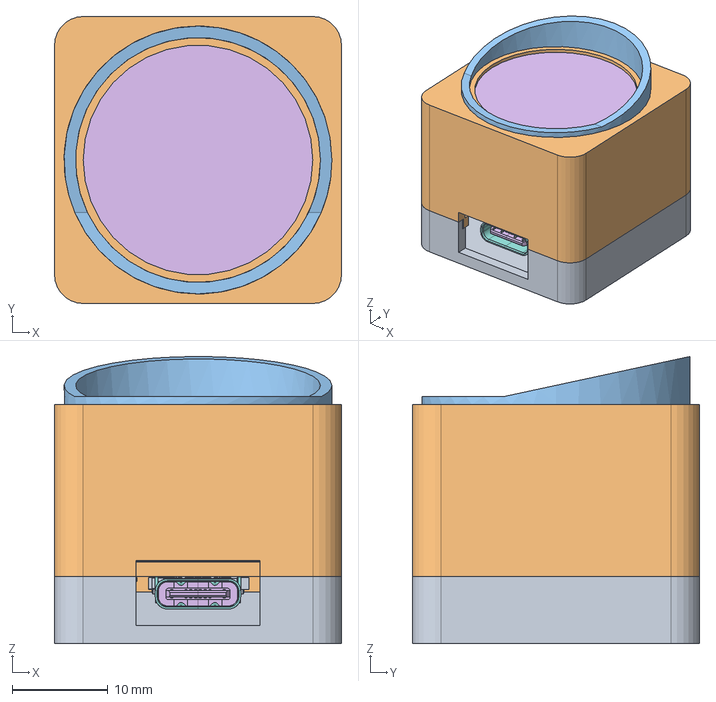
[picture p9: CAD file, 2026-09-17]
SL25-RevB/enclosure/sl25_traffic_rev_b/cad/SL25_Traffic_B_assembly.step
30.0 x 30.0 x 30.0 mm

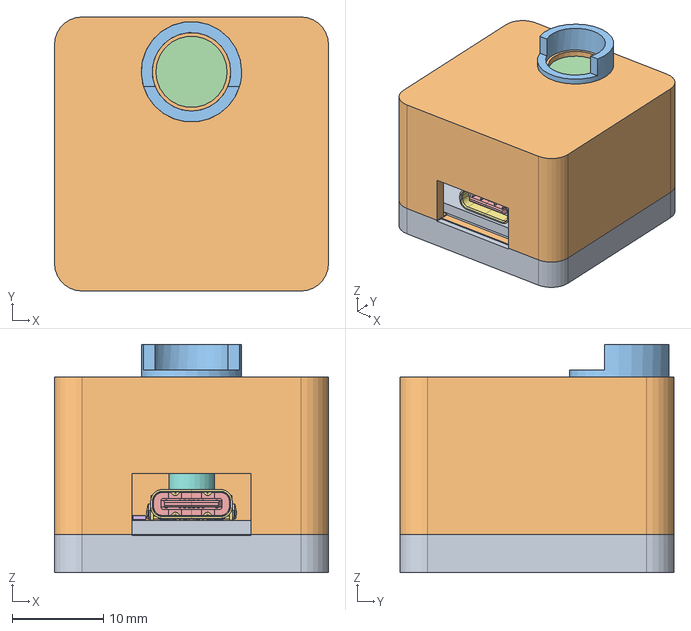
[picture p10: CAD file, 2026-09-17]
enclosure/sl25_traffic/cad/SL25_Traffic_A_assembly.step
30.0 x 30.0 x 25.0 mm

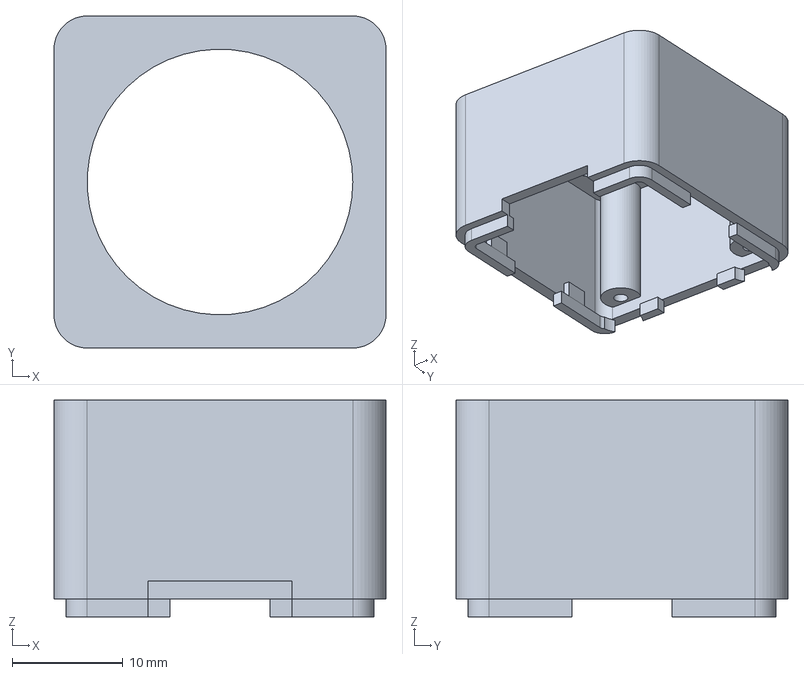
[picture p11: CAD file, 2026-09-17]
enclosure/cad_step/02_front_housing.step
30.0 x 30.0 x 19.6 mm

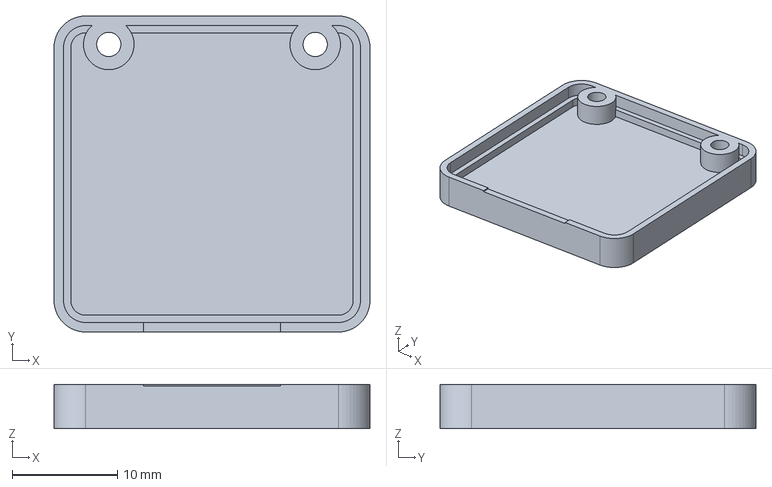
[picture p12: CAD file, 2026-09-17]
enclosure/sl25_traffic/cad/01_rear_cover.step
30.0 x 30.0 x 4.20 mm

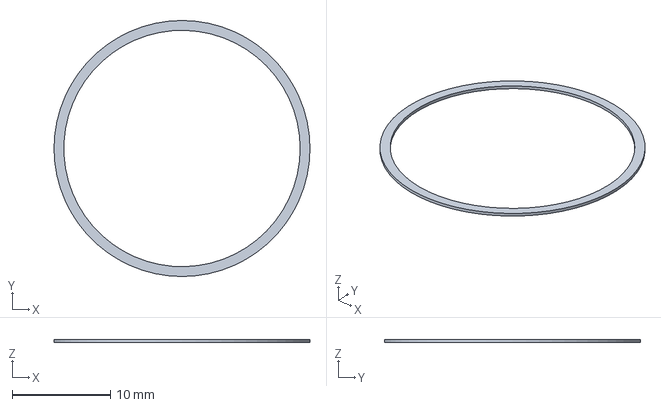
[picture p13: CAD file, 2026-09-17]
enclosure/sl25_traffic_rev_b/package_staging_20260905/cad_step/07_foam_gasket.step
26.0 x 26.0 x 0.3 mm

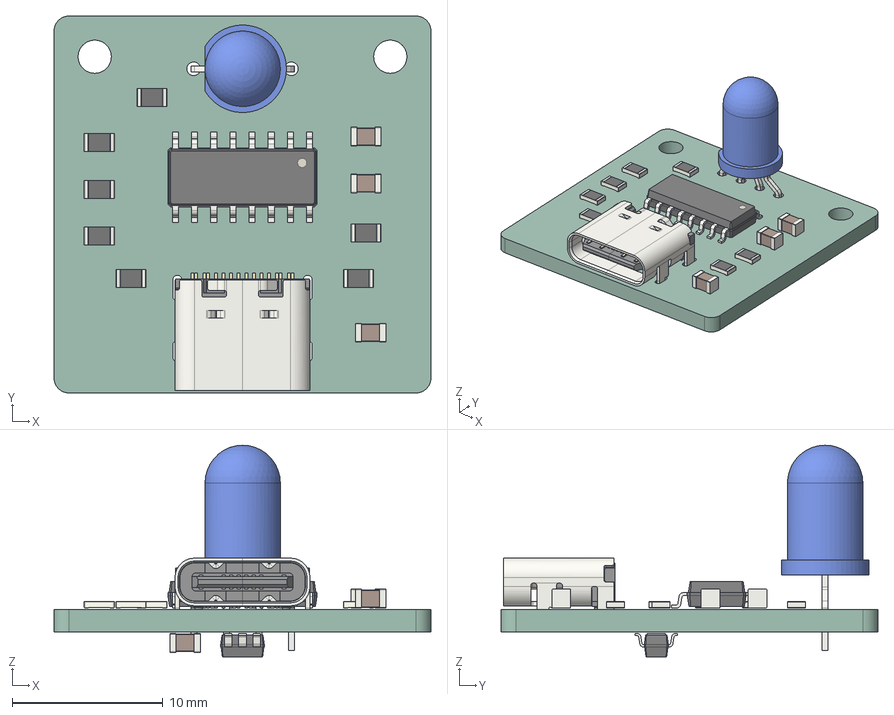
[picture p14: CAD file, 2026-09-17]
hardware/sl25/mechanical/sl25.step
25.0 x 25.0 x 14.0 mm
C_0805_2012Metric x 4
R_0805_2012Metric x 7
SOIC-16_3.9x9.9mm_P1.27mm
LED_D5.0mm-4_RGB_Wide_Pins
USB_C_Receptacle_16P_TopMnt_Horizontal_GCT_USB4105-xx-A
SOT-23-6
sl25_PCB

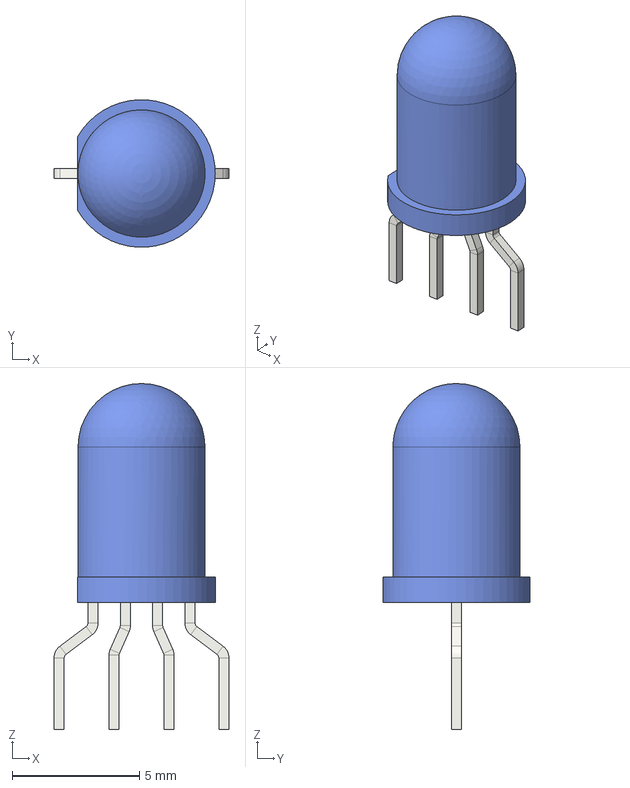
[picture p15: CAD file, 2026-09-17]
hardware/sl25/models/LED_D5.0mm-4_RGB_Wide_Pins.step
6.88 x 5.79 x 13.6 mm

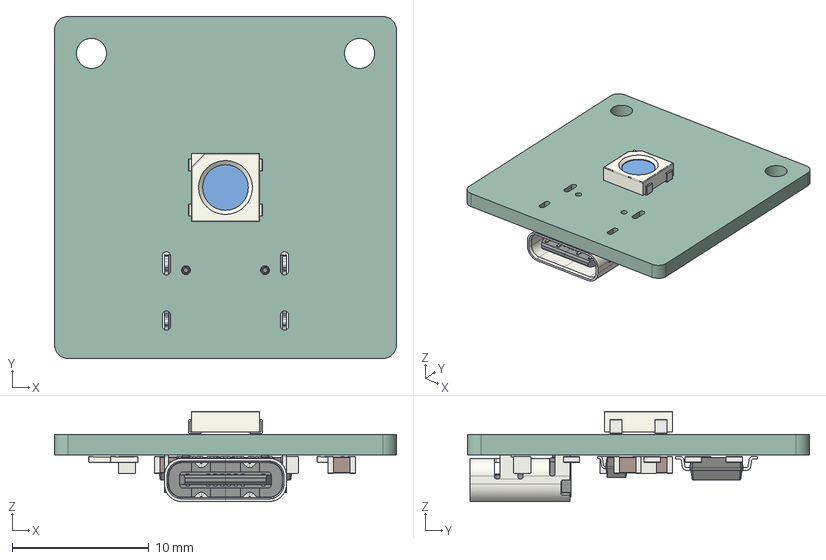
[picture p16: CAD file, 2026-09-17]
hardware/sl25_rev_b/mechanical/sl25.step
25.0 x 25.0 x 6.59 mm
LED_WS2812B_PLCC4_50x50mm_P32mm
C_0805_2012Metric x 5
R_0805_2012Metric x 6
SOT-23-6
USB_C_Receptacle_16P_TopMnt_Horizontal_GCT_USB4105-xx-A
SOIC-16_3.9x9.9mm_P1.27mm
sl25_PCB

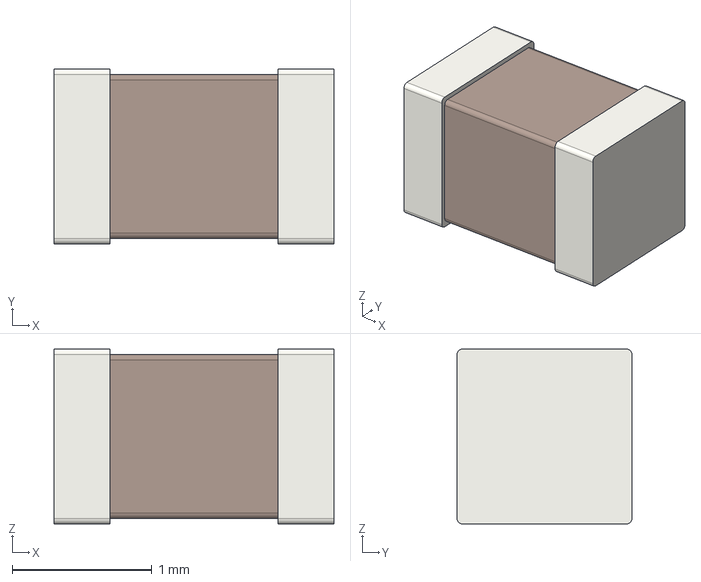
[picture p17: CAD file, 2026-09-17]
hardware/sl25_rev_b/models/C_0805_2012Metric.step
2.00 x 1.25 x 1.25 mm

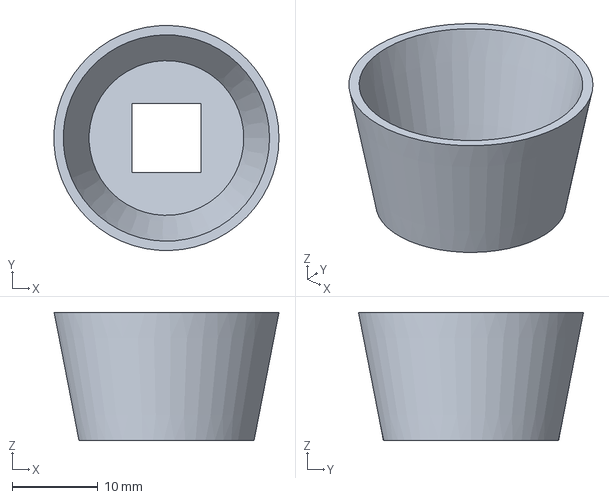
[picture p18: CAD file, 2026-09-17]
SL25-RevB/enclosure/sl25_traffic_rev_b/cad/04_mixing_cup.step
26.2 x 26.2 x 14.9 mm

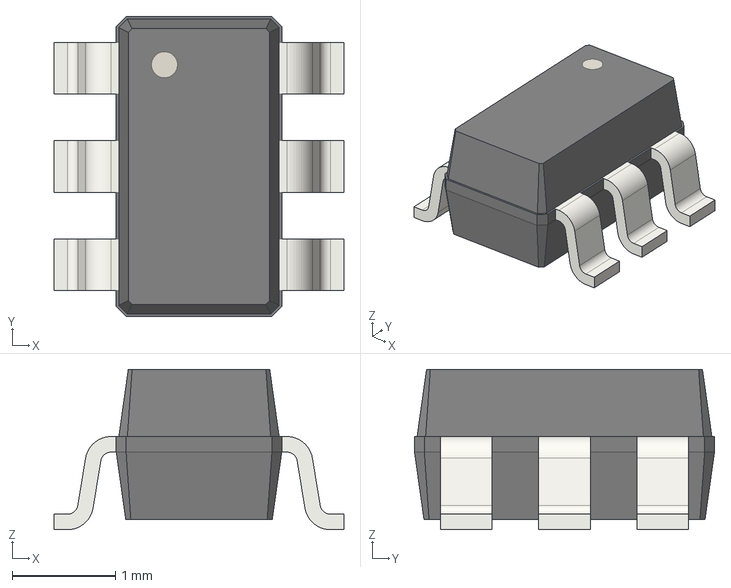
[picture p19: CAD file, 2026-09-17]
SL25-RevB/hardware/sl25_rev_b/models/SOT-23-6.step
2.80 x 2.90 x 1.55 mm

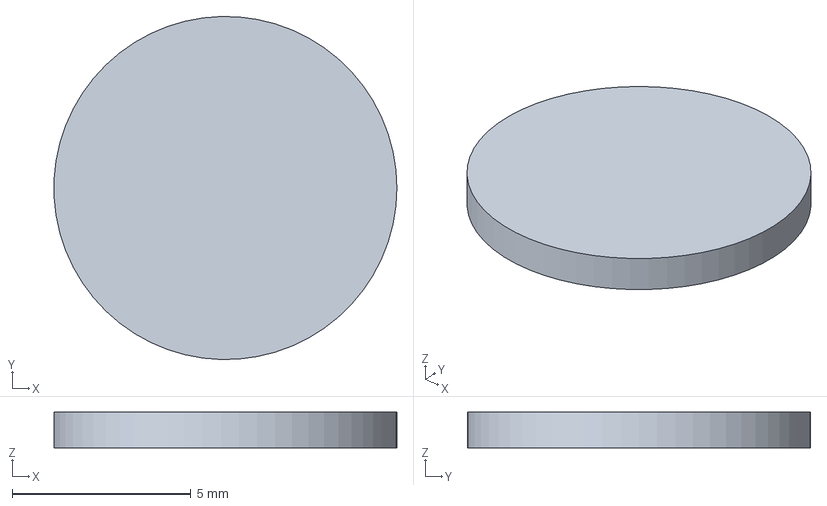
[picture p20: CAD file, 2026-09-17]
enclosure/sl25_traffic/cad/04_diffuser.step
9.59 x 9.60 x 1.00 mm

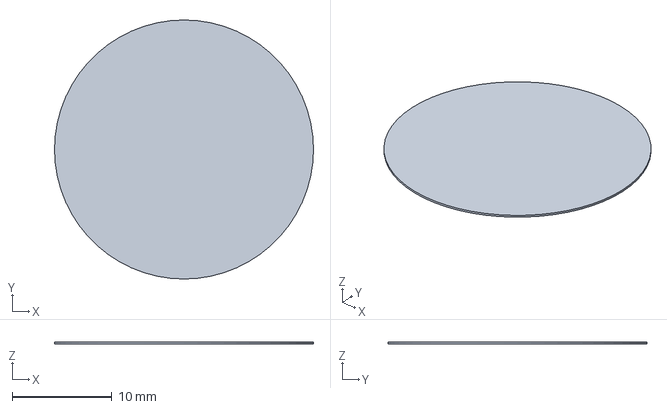
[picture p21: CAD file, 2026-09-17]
enclosure/sl25_traffic_rev_b/package_staging_20260905/cad_step/05_diffusion_film.step
26.0 x 26.0 x 0.2 mm

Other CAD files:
hardware/sl25/models/USB_C_Receptacle_GCT_USB4105-xx-A_16P_TopMnt_Horizontal.step
SL25-RevB/enclosure/sl25_traffic_rev_b/cad/01_rear_cover.step
SL25-RevB/enclosure/sl25_traffic_rev_b/cad/02_front_housing.step
SL25-RevB/enclosure/sl25_traffic_rev_b/cad/03_signal_hood.step
SL25-RevB/enclosure/sl25_traffic_rev_b/cad/05_diffusion_film.step
SL25-RevB/enclosure/sl25_traffic_rev_b/cad/06_clear_protector.step
SL25-RevB/enclosure/sl25_traffic_rev_b/cad/07_foam_gasket.step
SL25-RevB/enclosure/sl25_traffic_rev_b/cad/SL25_Traffic_B.FCStd
SL25-RevB/enclosure/sl25_traffic_rev_b/stl/01_rear_cover.stl
SL25-RevB/enclosure/sl25_traffic_rev_b/stl/02_front_housing.stl
SL25-RevB/enclosure/sl25_traffic_rev_b/stl/03_signal_hood.stl
SL25-RevB/enclosure/sl25_traffic_rev_b/stl/04_mixing_cup.stl
SL25-RevB/hardware/sl25_rev_b/models/LED_WS2812B_PLCC4_5.0x5.0mm_P3.2mm.step
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

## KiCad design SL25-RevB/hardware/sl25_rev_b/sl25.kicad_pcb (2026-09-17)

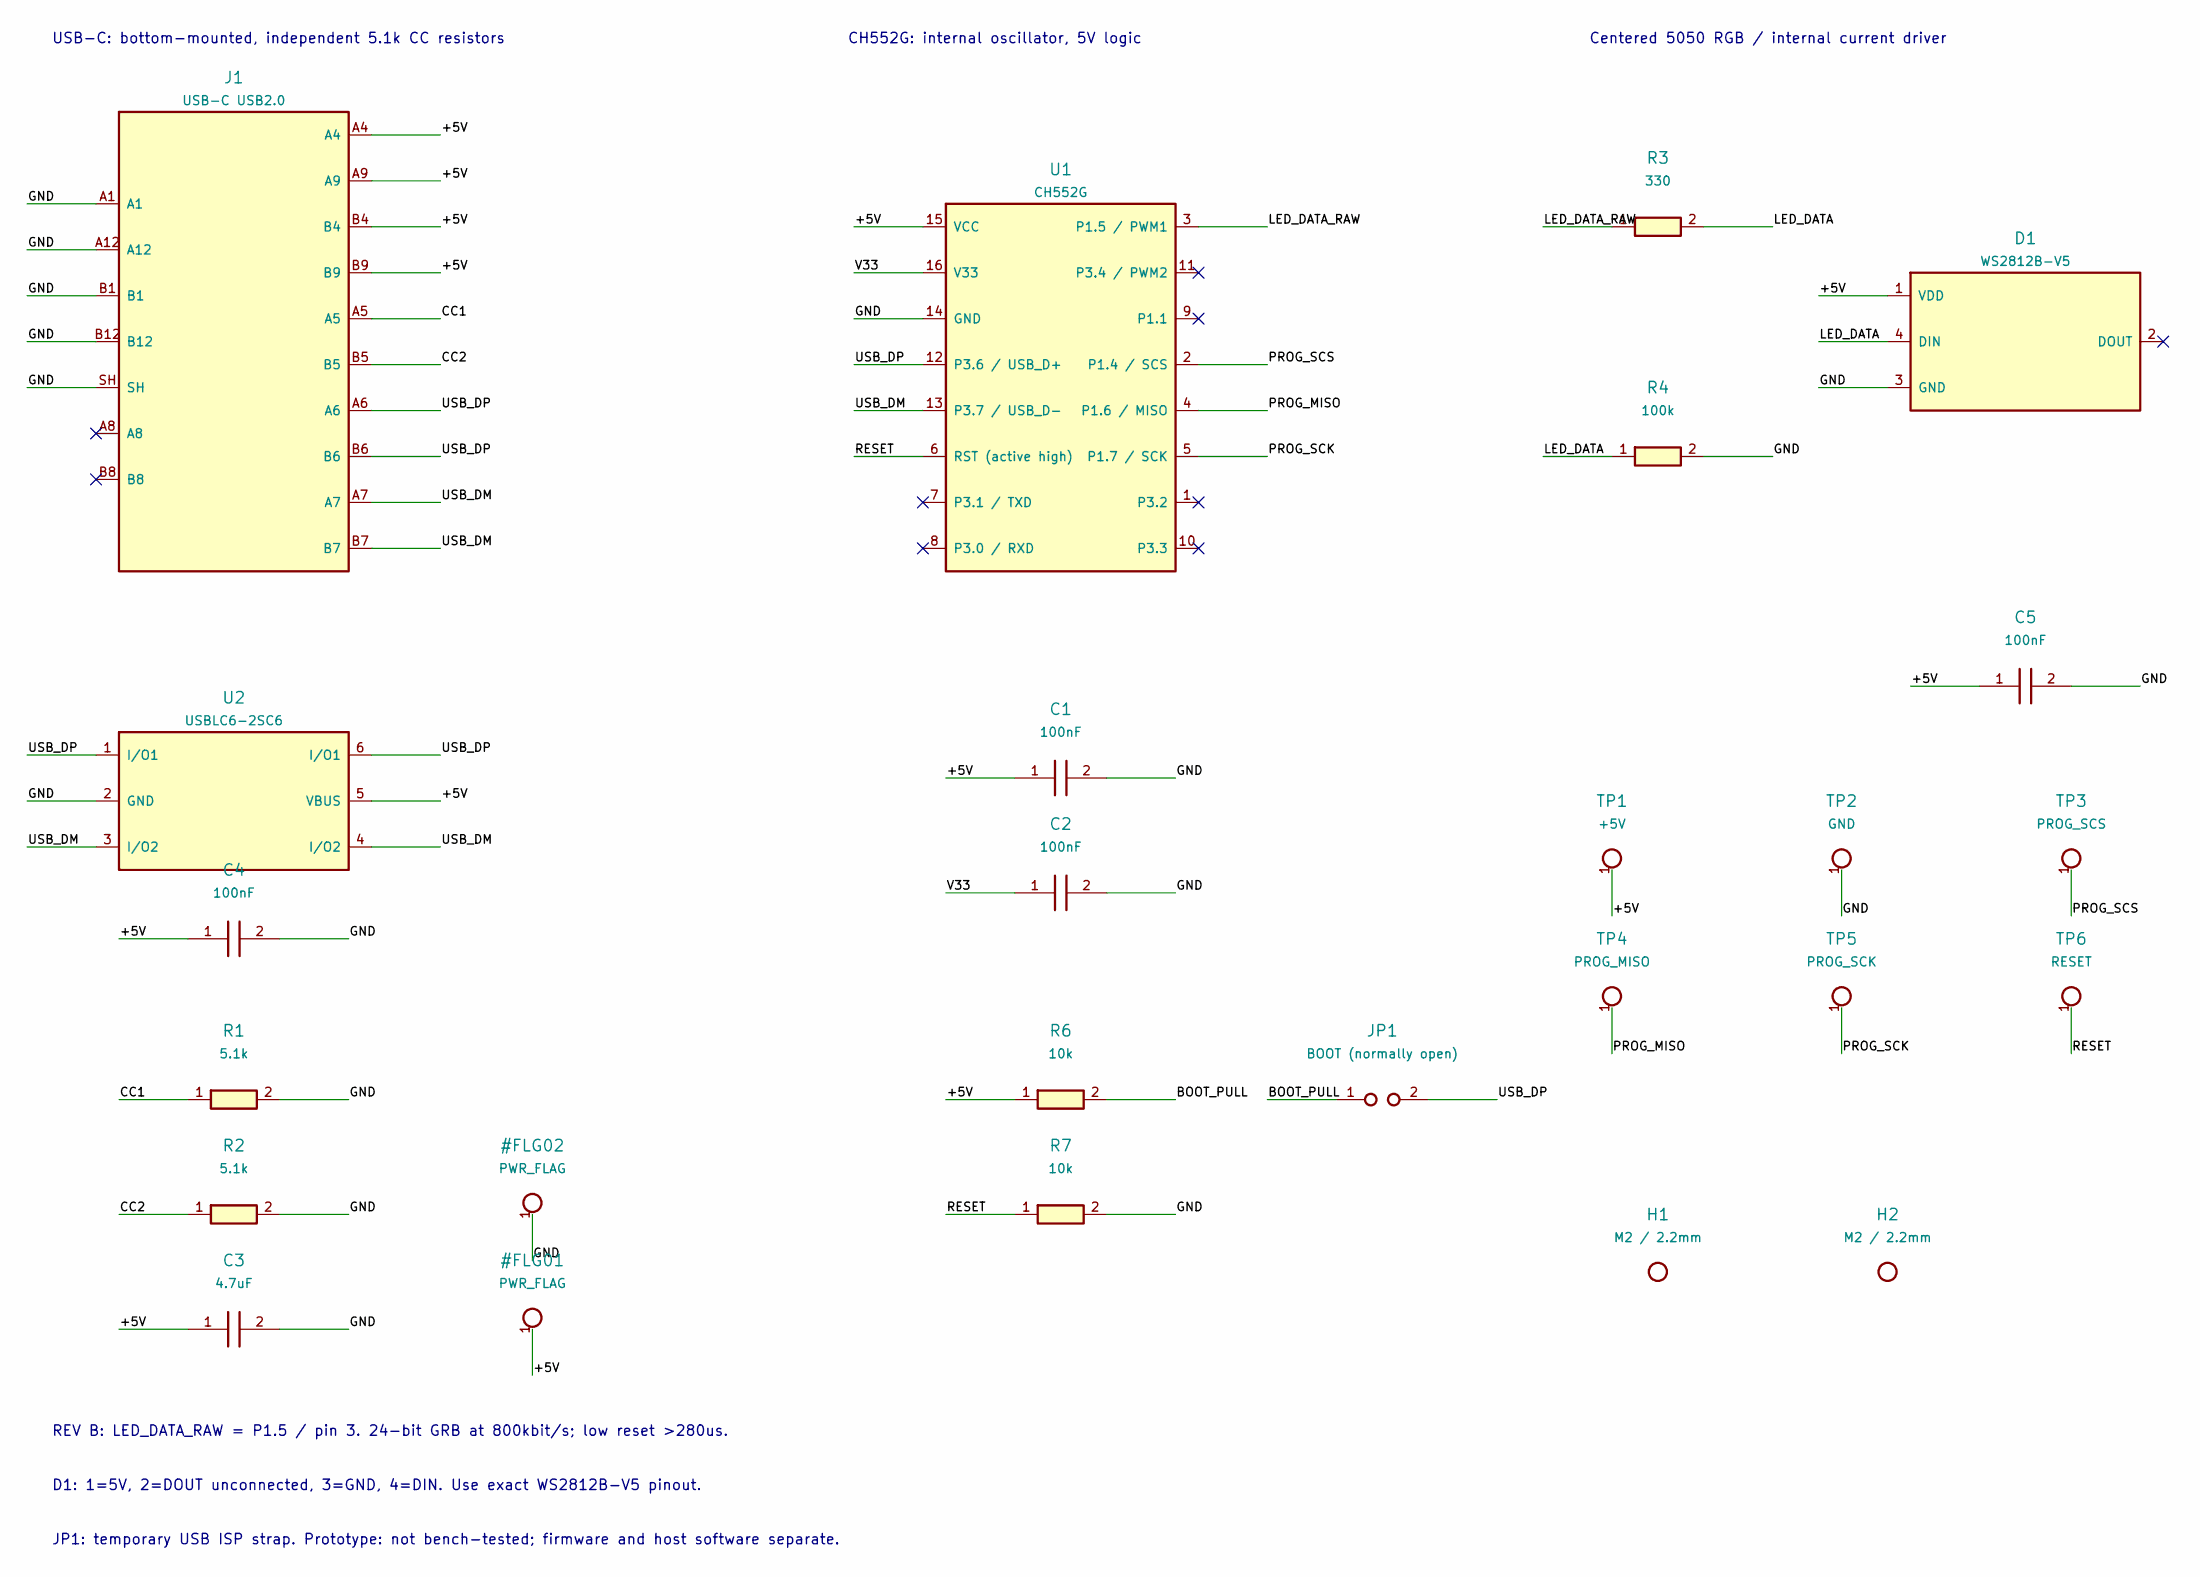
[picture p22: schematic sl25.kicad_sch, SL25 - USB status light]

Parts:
C1, C2, C4, C5: 100nF; C_0805_2012Metric
C3: 4.7uF; C_0805_2012Metric
D1: WS2812B-V5; LED_WS2812B_PLCC4_5.0x5.0mm_P3.2mm
H1, H2: M2 / 2.2mm; MountingHole_2.2mm_M2
J1: USB-C USB2.0; USB_C_Receptacle_GCT_USB4105-xx-A_16P_TopMnt_Horizontal
JP1: BOOT (normally open); SolderJumper-2_P1.3mm_Open_RoundedPad1.0x1.5mm
R1, R2: 5.1k; R_0805_2012Metric
R3: 330; R_0805_2012Metric
R4: 100k; R_0805_2012Metric
R6, R7: 10k; R_0805_2012Metric
TP1: +5V; TestPoint_Pad_D1.0mm
TP2: GND; TestPoint_Pad_D1.0mm
TP3: PROG_SCS; TestPoint_Pad_D1.0mm
TP4: PROG_MISO; TestPoint_Pad_D1.0mm
TP5: PROG_SCK; TestPoint_Pad_D1.0mm
TP6: RESET; TestPoint_Pad_D1.0mm
U1: CH552G; SOIC-16_3.9x9.9mm_P1.27mm
U2: USBLC6-2SC6; SOT-23-6

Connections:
/+5V: C1.1, C3.1, C4.1, C5.1, D1.1 (VDD), J1.A4, J1.A9, J1.B4, J1.B9, R6.1, TP1.1, U1.15 (VCC), U2.5 (VBUS)
/BOOT_PULL: JP1.1, R6.2
/CC1: J1.A5, R1.1
/CC2: J1.B5, R2.1
/GND: C1.2, C2.2, C3.2, C4.2, C5.2, D1.3 (GND), J1.A1, J1.A12, J1.B1, J1.B12, J1.SH, R1.2, R2.2, R4.2, R7.2, TP2.1, U1.14 (GND), U2.2 (GND)
/LED_DATA: D1.4 (DIN), R3.2, R4.1
/LED_DATA_RAW: R3.1, U1.3 (P1.5 / PWM1)
/PROG_MISO: TP4.1, U1.4 (P1.6 / MISO)
/PROG_SCK: TP5.1, U1.5 (P1.7 / SCK)
/PROG_SCS: TP3.1, U1.2 (P1.4 / SCS)
/RESET: R7.1, TP6.1, U1.6 (RST (active high))
/USB_DM: J1.A7, J1.B7, U1.13 (P3.7 / USB_D-), U2.3 (I/O2), U2.4 (I/O2)
/USB_DP: J1.A6, J1.B6, JP1.2, U1.12 (P3.6 / USB_D+), U2.1 (I/O1), U2.6 (I/O1)
/V33: C2.1, U1.16 (V33)

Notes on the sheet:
USB-C: bottom-mounted, independent 5.1k CC resistors
CH552G: internal oscillator, 5V logic
Centered 5050 RGB / internal current driver
REV B: LED_DATA_RAW = P1.5 / pin 3. 24-bit GRB at 800kbit/s; low reset >280us.
D1: 1=5V, 2=DOUT unconnected, 3=GND, 4=DIN. Use exact WS2812B-V5 pinout.
JP1: temporary USB ISP strap. Prototype: not bench-tested; firmware and host software separate.

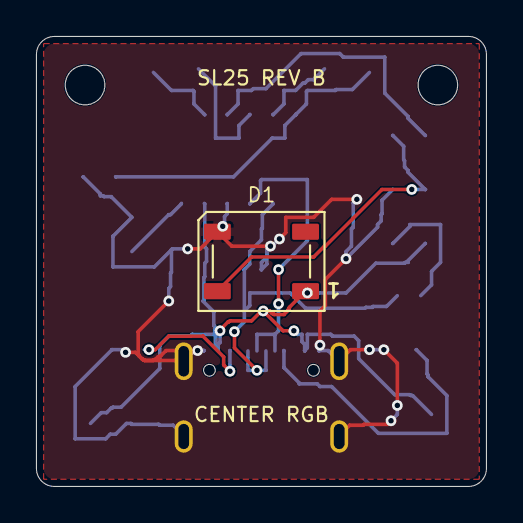
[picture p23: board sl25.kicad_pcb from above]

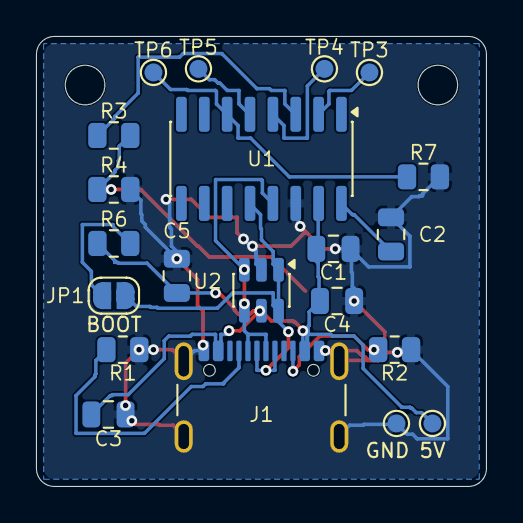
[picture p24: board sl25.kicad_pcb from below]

Board: 2 copper layers, 25.0 x 25.0 mm, 24 parts (21 on the bottom side), 14 nets.

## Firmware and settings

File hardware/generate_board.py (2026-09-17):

"""Rebuild the SL25 prototype in KiCad's bundled Python (pcbnew required)."""
from pathlib import Path
import csv
import json
import math
import os
import subprocess
import uuid
import xml.etree.ElementTree as ET
import pcbnew as pcb

ROOT = Path(__file__).resolve().parent
OUT = ROOT / "sl25"
LIB = Path(os.environ.get("KICAD_FOOTPRINT_DIR", "E:/Kicard/share/kicad/footprints"))
NAME = "sl25"
REVISION = "A"
SCHEMATIC_NOTES = None
BOARD_TEXT = None
NS = uuid.UUID("5a8e4c42-de27-4d84-90f6-7883a3b62e90")
uid = lambda s: str(uuid.uuid5(NS, s))
SHEET = uid("sheet")


def quote(s):
    return json.dumps(str(s), ensure_ascii=True)


def pin(num, name, x, y, angle, kind="passive"):
    return dict(num=str(num), name=name, x=x, y=y, angle=angle, kind=kind)


def box_pins(left, right):
    result = []
    for side, items in [(0, left), (1, right)]:
        for i, item in enumerate(items):
            n, name, kind = item
            result.append(pin(n, name, -15.24 if not side else 15.24,
                              (len(items)-1)*2.54-i*5.08, 0 if not side else 180, kind))
    return result


SYMS = {
    "R": [pin(1, "~", -5.08, 0, 0), pin(2, "~", 5.08, 0, 180)],
    "C": [pin(1, "~", -5.08, 0, 0), pin(2, "~", 5.08, 0, 180)],
    "Jumper": [pin(1, "~", -5.08, 0, 0), pin(2, "~", 5.08, 0, 180)],
    "TestPoint": [pin(1, "~", 0, 0, 90)],
    "Mount": [],
    "PowerFlag": [pin(1, "~", 0, 0, 90, "power_out")],
    "CH552G": box_pins(
        [(15,"VCC","power_in"),(16,"V33","power_out"),(14,"GND","power_in"),
         (12,"P3.6 / USB_D+","bidirectional"),(13,"P3.7 / USB_D-","bidirectional"),
         (6,"RST (active high)","input"),(7,"P3.1 / TXD","bidirectional"),(8,"P3.0 / RXD","bidirectional")],
        [(3,"P1.5 / PWM1","bidirectional"),(11,"P3.4 / PWM2","bidirectional"),(9,"P1.1","bidirectional"),
         (2,"P1.4 / SCS","bidirectional"),(4,"P1.6 / MISO","bidirectional"),(5,"P1.7 / SCK","bidirectional"),
         (1,"P3.2","bidirectional"),(10,"P3.3","bidirectional")]),
    "USB_C": box_pins(
        [(n,n,"passive") for n in ["A1","A12","B1","B12","SH","A8","B8"]],
        [(n,n,"passive") for n in ["A4","A9","B4","B9","A5","B5","A6","B6","A7","B7"]]),
    "USBLC6": box_pins([(1,"I/O1","passive"),(2,"GND","power_in"),(3,"I/O2","passive")],
                           [(6,"I/O1","passive"),(5,"VBUS","power_in"),(4,"I/O2","passive")]),
    "RGB": [pin(1,"RED",-10.16,5.08,0), pin(3,"BLUE",-10.16,0,0),
            pin(4,"GREEN",-10.16,-5.08,0), pin(2,"COMMON K",10.16,0,180)],
}

parts = []


def part(ref, kind, value, fp, xy, sch, nets, angle=0, back=False, mpn="", note=""):
    p = dict(ref=ref, kind=kind, value=value, fp=fp, xy=xy, sch=sch,
             nets={str(k):v for k,v in nets.items()}, angle=angle, back=back,
             mpn=mpn or value, note=note, uuid=uid(ref))
    parts.append(p)
    return p


res_fp = "Resistor_SMD:R_0805_2012Metric"
cap_fp = "Capacitor_SMD:C_0805_2012Metric"
tp_fp = "TestPoint:TestPoint_Pad_D1.0mm"
part("J1","USB_C","USB-C USB2.0","Connector_USB:USB_C_Receptacle_GCT_USB4105-xx-A_16P_TopMnt_Horizontal",
     (112.5,121.15),(43.18,53.34),
     dict(A1="GND",A12="GND",B1="GND",B12="GND",SH="GND",A4="+5V",A9="+5V",B4="+5V",B9="+5V",
          A5="CC1",B5="CC2",A6="USB_DP",B6="USB_DP",A7="USB_DM",B7="USB_DM",A8=None,B8=None),
     mpn="GCT USB4105-GF-A",note="Exact footprint required; USB-C socket is not interchangeable by appearance.")
part("U1","CH552G","CH552G","Package_SO:SOIC-16_3.9x9.9mm_P1.27mm",
     (112.5,110.7),(134.62,58.42),
     {15:"+5V",16:"V33",14:"GND",12:"USB_DP",13:"USB_DM",6:"RESET",7:None,8:None,
      3:"PWM_RED",11:"PWM_GREEN",9:"GPIO_BLUE",2:"PROG_SCS",4:"PROG_MISO",5:"PROG_SCK",1:None,10:None},
     angle=270,note="SOP16 150mil. Buy with factory USB ISP bootloader; do not substitute CH552T/E/P.")
part("U2","USBLC6","USBLC6-2SC6","Package_TO_SOT_SMD:SOT-23-6",
     (112.5,114.7),(43.18,104.14),{1:"USB_DP",6:"USB_DP",3:"USB_DM",4:"USB_DM",2:"GND",5:"+5V"},
     angle=270,back=True,note="Bottom side; pins 1/6 and 3/4 are internally connected line pairs.")
part("D1","RGB","WP154A4SUREQBFZGC","LED_THT:LED_D5.0mm-4_RGB_Wide_Pins",
     (109.2615,103.5),(241.3,53.34),{1:"LED_RED",2:"GND",3:"LED_BLUE",4:"LED_GREEN"},
     note="Form 1.27mm native leads to 2.159mm PCB pitch with 3mm standoff. 1=R, 2=common K, 3=B, 4=G. Clear lens needs diffuser.")
for ref,value,xy,sch,nets in [
    ("R1","5.1k",(105.1,117.4),(43.18,137.16),{1:"CC1",2:"GND"}),
    ("R2","5.1k",(120.2,117.4),(43.18,149.86),{1:"CC2",2:"GND"}),
    ("R3","1k",(103.0,108.4),(200.66,40.64),{1:"PWM_RED",2:"LED_RED"}),
    ("R4","1k",(103.0,111.5),(200.66,66.04),{1:"PWM_GREEN",2:"LED_GREEN"}),
    ("R5","1k",(103.0,114.6),(200.66,53.34),{1:"GPIO_BLUE",2:"LED_BLUE"}),
    ("R6","10k",(120.7,114.4),(134.62,137.16),{1:"+5V",2:"BOOT_PULL"}),
    ("R7","10k",(106.5,105.4),(134.62,149.86),{1:"RESET",2:"GND"}),
]:
    part(ref,"R",value,res_fp,xy,sch,nets,mpn=f"0805 {value} 1% >=0.125W")
for ref,value,xy,sch,nets in [
    ("C1","100nF",(120.7,111.1),(134.62,101.6),{1:"+5V",2:"GND"}),
    ("C2","100nF",(120.7,108.0),(134.62,114.3),{1:"V33",2:"GND"}),
    ("C3","1uF",(121.0,121.0),(43.18,162.56),{1:"+5V",2:"GND"}),
    ("C4","100nF",(108.7,114.7),(43.18,119.38),{1:"+5V",2:"GND"}),
]:
    part(ref,"C",value,cap_fp,xy,sch,nets,back=(ref=="C4"),mpn=f"0805 {value} X7R 16V")
part("JP1","Jumper","BOOT (normally open)","Jumper:SolderJumper-2_P1.3mm_Open_RoundedPad1.0x1.5mm",
     (120.7,114.4),(170.18,137.16),{1:"BOOT_PULL",2:"USB_DP"},back=True,
     mpn="PCB touch pads",note="Momentarily bridge during USB insertion; release after ISP enumeration. Do not solder closed.")
for i,(net,xy) in enumerate([("+5V",(103,121.5)),("GND",(105,121.5)),("PROG_SCS",(106.5,102.0)),
                            ("PROG_MISO",(109.0,101.8)),("PROG_SCK",(116.0,101.8)),("RESET",(118.5,102.0))],1):
    part(f"TP{i}","TestPoint",net,tp_fp,xy,(195.58+(i-1)%3*25.4,111.76+(i-1)//3*15.24),{1:net},back=True,
         mpn="PCB test pad",note="Programmer pads use 5V signaling; disconnect USB before external power.")
for i,x in enumerate([102.7,122.3],1):
    part(f"H{i}","Mount","M2 / 2.2mm","MountingHole:MountingHole_2.2mm_M2",(x,102.7),
         (200.66+(i-1)*25.4,157.48),{},mpn="M2 mounting hole")


def effects(size=1.0, extra=""):
    return f'(effects (font (size {size} {size})) {extra})'
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

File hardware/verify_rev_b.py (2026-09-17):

"""Verify schematic/PCB/optical interface invariants for the coordinated Rev B."""
from pathlib import Path
import hashlib
import json
import math
import pcbnew as pcb

root = Path(__file__).resolve().parent / "sl25_rev_b"
board = pcb.LoadBoard(str(root / "sl25.kicad_pcb"))
fps = {f.GetReference(): f for f in board.GetFootprints()}


def net(ref, pin):
    values = {p.GetNetname().lstrip('/') for p in fps[ref].Pads() if p.GetNumber() == str(pin)}
    assert len(values) == 1, (ref, pin, values)
    return values.pop()


for pin, expected in {3: "LED_DATA_RAW", 12: "USB_DP", 13: "USB_DM", 14: "GND",
                      15: "+5V", 16: "V33", 6: "RESET", 2: "PROG_SCS",
                      4: "PROG_MISO", 5: "PROG_SCK"}.items():
    assert net("U1", pin) == expected
for pin, expected in {1: "+5V", 3: "GND", 4: "LED_DATA"}.items():
    assert net("D1", pin) == expected
assert net("D1", 2).startswith("unconnected-")
assert fps["D1"].GetValue() == "WS2812B-V5"
assert fps["D1"].GetLayer() == pcb.F_Cu
assert abs(fps["D1"].GetOrientationDegrees() - 180) < 1e-6
assert math.dist(tuple(pcb.ToMM(fps["D1"].GetPosition())), (112.5, 112.5)) < 1e-6
for ref, fp in fps.items():
    if ref not in ("D1", "H1", "H2"):
        assert fp.GetLayer() == pcb.B_Cu, ref
assert net("R3", 1) == "LED_DATA_RAW" and net("R3", 2) == "LED_DATA"
assert fps["R3"].GetValue() == "330"
assert net("R4", 1) == "LED_DATA" and net("R4", 2) == "GND"
assert fps["R4"].GetValue() == "100k" and "R5" not in fps
for ref in ("C1", "C3", "C4", "C5"):
    assert net(ref, 1) == "+5V" and net(ref, 2) == "GND"
assert net("C2", 1) == "V33" and net("C2", 2) == "GND"
assert fps["C3"].GetValue() == "4.7uF"
for pin, expected in {"A6": "USB_DP", "B6": "USB_DP", "A7": "USB_DM", "B7": "USB_DM",
                      "A5": "CC1", "B5": "CC2", "SH": "GND"}.items():
    assert net("J1", pin) == expected
assert net("R1", 1) == "CC1" and net("R2", 1) == "CC2"
assert net("R1", 2) == net("R2", 2) == "GND"
assert net("R6", 1) == "+5V" and net("R6", 2) == net("JP1", 1) == "BOOT_PULL"
assert net("JP1", 2) == "USB_DP"
assert net("R7", 1) == "RESET" and net("R7", 2) == "GND"
assert board.GetCopperLayerCount() == 2
assert abs(pcb.ToMM(board.GetDesignSettings().GetBoardThickness()) - 1.6) < 1e-6
for ref, position in [("H1", (102.7, 102.7)), ("H2", (122.3, 102.7))]:
    assert math.dist(tuple(pcb.ToMM(fps[ref].GetPosition())), position) < 1e-6
    assert abs(pcb.ToMM(next(iter(fps[ref].Pads())).GetDrillSize().x) - 2.2) < 1e-6
for fp in fps.values():
    for model in fp.Models():
        assert model.m_Filename.startswith("${KIPRJMOD}/models/")
        assert (root / model.m_Filename.replace("${KIPRJMOD}/", "")).is_file()
for phrase in ("Found 0 DRC violations", "Found 0 unconnected pads", "Found 0 Footprint errors"):
    assert phrase in (root / "checks/drc.rpt").read_text(encoding="utf-8")
erc = (root / "checks/erc.rpt").read_text(encoding="utf-8")
assert "Errors 0" in erc and "Warnings 0" in erc
for name in ("sl25-PTH.drl", "sl25-NPTH.drl", "sl25-F_Cu.gtl", "sl25-B_Cu.gbl", "sl25-Edge_Cuts.gm1"):
    assert (root / "fabrication" / name).stat().st_size > 100
step = (root / "mechanical/sl25.step").read_text(encoding="utf-8")
assert "LED_WS2812B_PLCC4" in step and "SOIC-16_3.9x9.9mm" in step
parameters = json.loads((root.parents[1] / "enclosure/sl25_traffic_rev_b/parameters.json").read_text())
assert parameters["lens_center"] == [15, 15]
assert parameters["lens_aperture_diameter"] == 24

interface = {
    "revision": "B", "units": "mm",
    "coordinate_convention": "PCB top view; origin at top-left; x right, y down",
    "board": {"width": 25, "height": 25, "thickness": 1.6, "corner_radius": 1},
    "enclosure": {"width": 30, "height": 30, "depth_including_hood": 30},
    "mounting_holes": [{"ref": ref, "x": x, "y": 2.7, "diameter": 2.2}
                       for ref, x in [("H1", 2.7), ("H2", 22.3)]],
    "led": {"ref": "D1", "mpn": "WS2812B-V5", "side": "top", "optical_center": [12.5, 12.5],
            "body_size": [5.4, 5.0, 1.57], "height_allowance_above_pcb": 1.7,
            "rotation_degrees": 180, "pin3_notch_in_board_top_view": "upper-left"},
    "usb": {"ref": "J1", "mpn": "GCT USB4105-GF-A", "side": "bottom",
            "footprint_origin": [12.5, 21.15], "insertion_direction": "+Y",
            "clearance_below_pcb_min": 3.5},
    "optics": {"aperture_diameter": 24, "film_diameter": 26, "film_thickness": 0.2,
               "clear_PC_thickness": 0.5, "minimum_LED_to_film": 13.5,
               "enclosure_center": [15, 15]},
    "notes": ["Use only with Rev B enclosure.", "Geometry validated; no physical or optical test performed."]
}
(root / "mechanical/interface.json").write_text(json.dumps(interface, indent=2), encoding="utf-8")
result = {"revision": "B", "tool": pcb.Version(), "passed": True, "footprints": len(fps),
          "board_mm": [25, 25, 1.6], "copper_layers": 2,
          "erc_errors": 0, "erc_warnings": 0, "drc_violations": 0, "unconnected_pads": 0,
          "schematic_parity_issues": 0, "centered_source": True, "top_electronic_parts": ["D1"],
          "critical_pinmap_checks": "passed", "physical_validation": "not performed",
          "pcb_sha256": hashlib.sha256((root / "sl25.kicad_pcb").read_bytes()).hexdigest()}
(root / "checks/verification.json").write_text(json.dumps(result, indent=2), encoding="utf-8")
print(json.dumps(result, indent=2))

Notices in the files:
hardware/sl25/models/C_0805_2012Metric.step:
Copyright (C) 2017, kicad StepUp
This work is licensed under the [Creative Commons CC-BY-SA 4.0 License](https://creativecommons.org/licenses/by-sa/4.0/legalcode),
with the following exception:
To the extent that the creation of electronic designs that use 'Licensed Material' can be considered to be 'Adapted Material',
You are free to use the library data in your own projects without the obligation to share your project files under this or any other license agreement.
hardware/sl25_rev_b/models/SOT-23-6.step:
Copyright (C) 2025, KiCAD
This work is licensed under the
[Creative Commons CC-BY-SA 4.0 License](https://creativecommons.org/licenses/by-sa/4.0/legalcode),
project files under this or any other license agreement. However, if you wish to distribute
